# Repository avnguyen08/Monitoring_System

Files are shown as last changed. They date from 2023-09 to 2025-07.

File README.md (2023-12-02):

# Current Monitoring System 

Various current monitoring software products made on the ESP32 using varied electronic components including: LCDs, external ADC, potentiometers, capacitors, resistors, plug-and-play connectors, and 7 segment displays

### Version A (7-Segment Display)
ESP32 Feather Board paired with a Featherwing 7-Segment Display to display the amount of amps passing through a material and the amount of time the amps passed through for. The external ADC can handle voltage bursts as low as 2mv at 180 ms 
- Language: C++
 - Components: ESP32 Feather, external ADC, 7-segment display featherwing, LEDs, potentiometers, capacitors, resistors, socket connectors, pin head connectors, 5V power adapter.
- Description:
    Cycles between displaying the current and time on a 7-Segment display. Display times are customizable using potentiometers on back of PCB
    External pull down resistors and decoupling cacpacitors used for signal integrity.
    Dip switch in back to provide customizability with regard to different shunts and machines. 
    Machines operate at thousands of current and use a shunt to have readable levels, ranging from 2mv to 4V. 
    Pin headers and socket headers for easy installation into varied machines.

### Version B (LCD Display)
- Language: C++
- Components: LilyGo T Display S3, external ADC, capacitors, resistors, socket connectors, pin head connectors, 5V power adapter.
- Description: 
  Communication with LCD using SPI. Communication with external ADC using I2C. ESP32 simulatenously displays the amount of amps passing through a material and the amount of time the amps passed through for. Decoupling Capacitors and pull down resistors used for signal integrety. Pin headers and 
  socket headers for easy installation into varied machines.

### Version C (LCD Display + Hardware Filter)
 - Language: C++
 - Components: LilyGo T Display S3, external ADC, capacitors, resistors, socket connectors, pin head connectors, 5V power adapter, op amps, potentiometers.
 - Description: Communication with LCD using SPI, Communication with external ADC using I2C. ESP32 simulatenously displays the amount of amps passing through a material and the amount of time the amps passed through for. Decoupling Capacitors and pull down resistors used for signal integrety. Pin headers and socket headers for easy installation into varied machines. Integrated legacy hardware filter used to help clean up dirty signals caused by electromagnetic interference.

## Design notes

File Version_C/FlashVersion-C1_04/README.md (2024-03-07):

## Flash Firmware to LCD Tutorial for Windows(Current Monitoring System (Ver.C 1.04)

1. Unplug LCD screen from PCB board
2. Hold Down BOOT Button (Reference picture in folder)
3. Plug in your PC's USB-C cable into LCD Screen
4. Release BOOT Button
5. Click Flash.bat file to flash firmware

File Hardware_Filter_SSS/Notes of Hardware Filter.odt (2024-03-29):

R22 and R27 at 5k causes output to max out around .68 V even with potentiometer calibrating

The last op amp seems to output at a ratio of 7.196 at 500 mv dc input

its ratio is 7.197 at 100mv dc input

its ratio is 7.19 at 10 mv dc input

From input to first opamp output comparison

500mv to 2656 mV

100mv to 531.37 mV

10mv 53.137 mV

Meaning ratio is 5.3137

with -10mV input

3rd opamp output 53.136mV

Long line stays at 53.11

Long line feeds into + input of 5th opamp, also has .1uF capacitor

5th Opamp output is 72.78 mV

Theoretical Calculations:

1st Op Amp: 1+ 110/25.5 = 5.3137 ratio

2nd Op Amp: Full Wave Rectifier

3rd Op Amp: Unity Gain

4th Op Amp: Low Pass Filter?

5th Op Amp: Low Pass Filter? And 1+3.65/10 = 1.365 gain

Meaning DC input voltage to 5th Op Amp Output is: 5.3137*1.365 = 7.2532 gain

Sine Wave LTSPICE Test:

Note: 1st Op Amp may be 1 + 110/(22.5k||187k+13k[reactance of .2uF capacitor]) = 1 + 110k/22.62k = 5.86 Gain

Input of 100mv Amplitude sine wave

1st Op Amp: Output is 587 mV Amplitude

2nd Op Amp: 587 mV (rectified)

3rd Op Amp: 587 mV

Long Line 336.5mV

400mV

1v at input is .748v at 2x

2v at input is 1.38v at 2x

3V at input is 1.38V at 2x

.5v at input is .374 at 2x

Results suggest it is linear when changing the multiplier value of 1st opamp. (R3 from 110k to 25.5k). Should double the input going across the 1st op amp

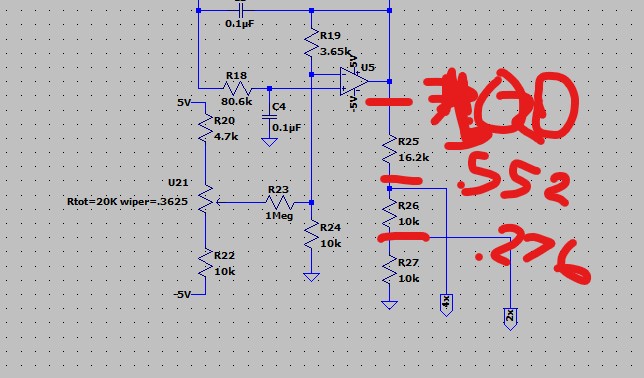
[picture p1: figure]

Working on Solution:

2.82V amplitude (2V rms) produces 16.56V

if I can turn 2.82V input into 5v then solution should work (1.77 gain)

1.77 = 1 + R3/25.5k

R3 = .77*25.5k = 19.635k

To do that I use 16.56V

LTSPICE Results

Right now best results is R3 as 17k and doing this voltage divider for last op amp

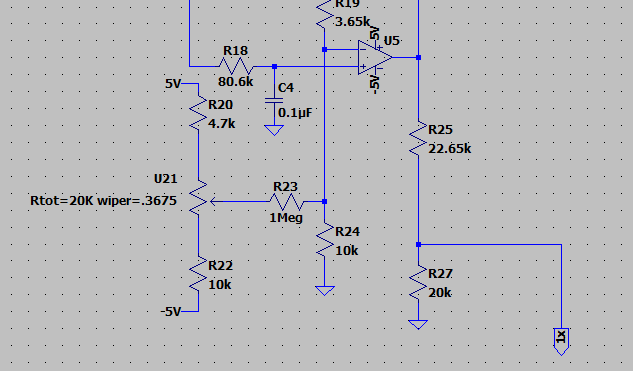
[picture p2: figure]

Next steps:

I notice with dc values when I run 1V I expect 1V at the 1x output but I get 1.058V. That is a 58mV difference. Compared to the original of 1.987V which is a 11 mV difference. I hypothesize the difference is because I tuned the resistors in the circuit for sine wave outputs rather than dc. Do to impedance issues there are probably some differences. One way I think to change it is to mess with the first op amp r5 and c1 values.

First test. Default values of 187k and .1uF gets max value of 5.2456. Calculating the impedance, I get the value of 188.8k, 188.8k in parallel with 25.5k is 22.47

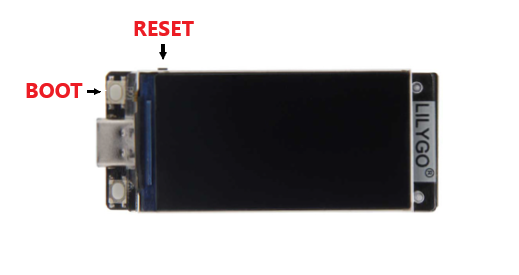
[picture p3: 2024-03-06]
Version_C/FlashVersion-C1_04/LCD Diagram.png

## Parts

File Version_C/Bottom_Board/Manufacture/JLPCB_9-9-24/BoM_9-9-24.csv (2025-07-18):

Comment | Designator | Footprint
LM324DR | U1,U2 | Package_SO:SOIC-14_3.9x8.7mm_P1.27mm
ADS1015IDGSR | U3 | bot_lib:DGS0010A_N
.75 Vdc | TP2 | TestPoint:TestPoint_Loop_D2.54mm_Drill1.5mm_Beaded
.55 Vdc | TP1 | TestPoint:TestPoint_Loop_D2.54mm_Drill1.5mm_Beaded
SW_DIP_x04 | SW1 | Button_Switch_THT:SW_DIP_SPSTx04_Slide_9.78x12.34mm_W7.62mm_P2.54mm
20K POT | RV1,RV2 | bot_lib:Potentiometer_Bourns_3386P_Vertical
22K | R8,R18 | Resistor_SMD:R_0603_1608Metric
4.7K | R6,R9 | Resistor_SMD:R_0603_1608Metric
80.6K | R5,R7,R16,R20 | Resistor_SMD:R_0603_1608Metric
10K | R3,R12,R13,R17,R19,R21,R23,R26,R27,R28,R29 | Resistor_SMD:R_0603_1608Metric
1M | R14,R22 | Resistor_SMD:R_0603_1608Metric
20k | R10B1 | Resistor_SMD:R_0603_1608Metric
20K | R10A1,R11 | Resistor_SMD:R_0603_1608Metric
3.9M | R30 | Resistor_SMD:R_0603_1608Metric
3.65K | R25 | Resistor_SMD:R_0603_1608Metric
16.2K | R24 | Resistor_SMD:R_0603_1608Metric
110K | R15 | Resistor_SMD:R_0603_1608Metric
1.82K | R4 | Resistor_SMD:R_0603_1608Metric
25.5K | R2 | Resistor_SMD:R_0603_1608Metric
187K | R1 | Resistor_SMD:R_0603_1608Metric
Conn_02x03_Top_Bottom | J1,J5 | bot_lib:PinSocket_2x03_P2.54mm_Vertical
DIN-5 | J4 | bot_lib:DIN_5_PIN
Screw_Terminal_01x04 | J3 | bot_lib:Terminal_Strip_4_Pin
Conn_01x03_Pin | J2 | Connector_PinHeader_2.54mm:PinHeader_1x03_P2.54mm_Vertical
1N4148WS | D1 | bot_lib:Diode_1N4148WS
0.1uF | C3,C4,C5,C7,C8,C10,C11 | Capacitor_SMD:C_0603_1608Metric
330uF | C1,C2 | Capacitor_THT:CP_Radial_D10.0mm_P5.00mm
1uF | C9 | Capacitor_SMD:C_0603_1608Metric
0.002uF | C6 | Capacitor_SMD:C_0603_1608Metric

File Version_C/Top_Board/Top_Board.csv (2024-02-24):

Source: | C:\Users\aaron\OneDrive\Desktop\repos\Monitoring_System\Version_B\Top_Board\Top_Board.kicad_sch
Date: | 2/23/2024 12:11:28 PM
Tool: | Eeschema (7.0.0)
Generator: | D:\MyPrograms\7.0\bin\scripting\plugins/bom_csv_grouped_by_value.py
Component Count: | 3
Collated Components:
Item | Qty | Reference(s) | Value | LibPart | Footprint | Datasheet | DNP
1 | 2 | J1, J2 | 90_Deg_Conn | Connector_Generic:Conn_02x03_Odd_Even | Connector_PinHeader_2.54mm:PinHeader_2x03_P2.54mm_Horizontal | ~
2 | 1 | U1 | T-Display-S3 | Voltage_Sensor_Timer:T-Display-S3 | Voltage_Sensor_Timer:T-Display-S3

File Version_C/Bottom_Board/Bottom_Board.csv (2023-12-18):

Source: | C:\Users\aaron\OneDrive\Desktop\repos\Work_SSS\Version_B\Bottom_Board\Bottom_Board.kicad_sch
Date: | 12/5/2023 2:48:59 PM
Tool: | Eeschema (7.0.0)
Generator: | D:\MyPrograms\7.0\bin\scripting\plugins/bom_csv_grouped_by_value.py
Component Count: | 46
Collated Components:
Item | Qty | Reference(s) | Value | LibPart | Footprint | Datasheet | DNP | Sim.Device | Sim.Pins
1 | 6 | C1, C4, C6, C7, C8, C9 | 0.1uF | Device:C | Capacitor_SMD:C_0603_1608Metric | ~
2 | 2 | C2, C3 | 330uF | Device:C_Polarized_US | Capacitor_THT:CP_Radial_D10.0mm_P5.00mm | ~
3 | 1 | C5 | 0.002uF | Device:C | Capacitor_SMD:C_0603_1608Metric | ~
4 | 1 | D1 | 1N914 | Diode:1N914 | Diode_SMD:D_0603_1608Metric | http://www.vishay.com/docs/85622/1n914.pdf |  |  | D | 1=K 2=A
5 | 2 | J1, J2 | Conn_02x03_Top_Bottom | Connector_Generic:Conn_02x03_Odd_Even | Connector_PinSocket_2.54mm:PinSocket_2x03_P2.54mm_Vertical | ~
6 | 1 | J3 | Screw_Terminal_01x06 | Connector:Screw_Terminal_01x06 | Connector_Phoenix_MSTB:PhoenixContact_MSTBA_2,5_6-G-5,08_1x06_P5.08mm_Horizontal | ~
7 | 1 | J5 | DIN-5 | Connector:DIN-5 | bot_lib:DIN_5_PIN | http://www.mouser.com/ds/2/18/40_c091_abd_e-75918.pdf
8 | 1 | JP1 | Jumper_3_Open | Jumper:Jumper_3_Open | Connector_PinHeader_2.54mm:PinHeader_1x03_P2.54mm_Vertical | ~
9 | 4 | R1, R20, R21, R22 | 80.6K | Device:R_US | Resistor_SMD:R_0603_1608Metric | ~
10 | 2 | R2, R17 | 4.7K | Device:R_US | Resistor_SMD:R_0603_1608Metric | ~
11 | 7 | R3, R9, R13, R14, R16, R19, R24 | 10K | Device:R_US | Resistor_SMD:R_0603_1608Metric | ~
12 | 1 | R4 | 30.1K | Device:R_US | Resistor_SMD:R_0603_1608Metric | ~
13 | 1 | R5 | 20K | Device:R_US | Resistor_SMD:R_0603_1608Metric | ~
14 | 1 | R6 | 1M | Device:R_US | Resistor_SMD:R_0603_1608Metric | ~
15 | 1 | R7 | 25.5K | Device:R_US | Resistor_SMD:R_0603_1608Metric | ~
16 | 1 | R8 | 3.65K | Device:R_US | Resistor_SMD:R_0603_1608Metric | ~
17 | 1 | R10 | 187K | Device:R_US | Resistor_SMD:R_0603_1608Metric | ~
18 | 1 | R11 | 110K | Device:R_US | Resistor_SMD:R_0603_1608Metric | ~
19 | 1 | R12 | 16.2K | Device:R_US | Resistor_SMD:R_0603_1608Metric | ~
20 | 2 | R15, R18 | 22K | Device:R_US | Resistor_SMD:R_0603_1608Metric | ~
21 | 1 | R23 | 1.82K | Device:R_US | Resistor_SMD:R_0603_1608Metric | ~
22 | 2 | RV1, RV2 | 20K | Device:R_Potentiometer_US | Potentiometer_THT:Potentiometer_Bourns_3386P_Vertical | ~
23 | 1 | SW2 | SW_DIP_x04 | Switch:SW_DIP_x04 | Button_Switch_THT:SW_DIP_SPSTx04_Slide_9.78x12.34mm_W7.62mm_P2.54mm | ~
24 | 1 | TP1 | .75 Vdc | Connector:TestPoint | TestPoint:TestPoint_Loop_D2.54mm_Drill1.5mm_Beaded | ~
25 | 1 | TP2 | .55 Vdc | Connector:TestPoint | TestPoint:TestPoint_Loop_D2.54mm_Drill1.5mm_Beaded | ~
26 | 2 | U1, U2 | LM324 | Amplifier_Operational:LM324 | Package_SO:SOIC-14_3.9x8.7mm_P1.27mm | http://www.ti.com/lit/ds/symlink/lm2902-n.pdf

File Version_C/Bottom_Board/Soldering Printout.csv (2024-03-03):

Reference | Value | Qty
C1,C2 | 330uF | 2
C3,C4,C5,C7,C8,C10,C11 | 0.1uF | 7
C6 | 0.002uF | 1
C9 | 1uF | 1
D1 | 1N4148WS | 1
J1,J5 | Conn_02x03_Top_Bottom | 2
J2 | Conn_01x03_Pin | 1
J3 | Screw_Terminal_01x04 | 1
J4 | DIN-5 | 1
R1 | 187K | 1
R2 | 25.5K | 1
R3,R12,R13,R17,R19,R21,R23 | 10K | 7
R4 | 1.82K | 1
R5,R7,R16,R20 | 80.6K | 4
R6,R9 | 4.7K | 2
R8,R18 | 22K | 2
R10 | 30.1K | 1
R11,RV1,RV2 | 20K | 3
R14,R22 | 1M | 2
R15 | 110K | 1
R24 | 16.2K | 1
R25 | 3.65K | 1
R26,R27,R28,R29 | 10k | 4
R30 | 3.9M | 1
SW1 | SW_DIP_x04 | 1
TP1 | .55 Vdc | 1
TP2 | .75 Vdc | 1
U1,U2 | LM324 | 2
U3 | ADS1015IDGSR | 1

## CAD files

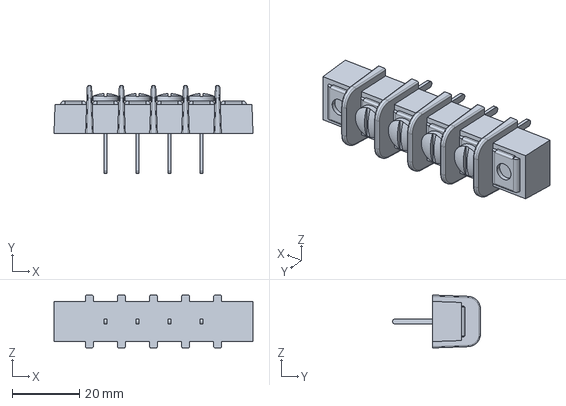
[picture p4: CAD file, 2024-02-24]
Version_C/Bottom_Board/Bottom_Board_3d/4_Pin_Terminal_Block.stp
59.2 x 26.2 x 15.7 mm

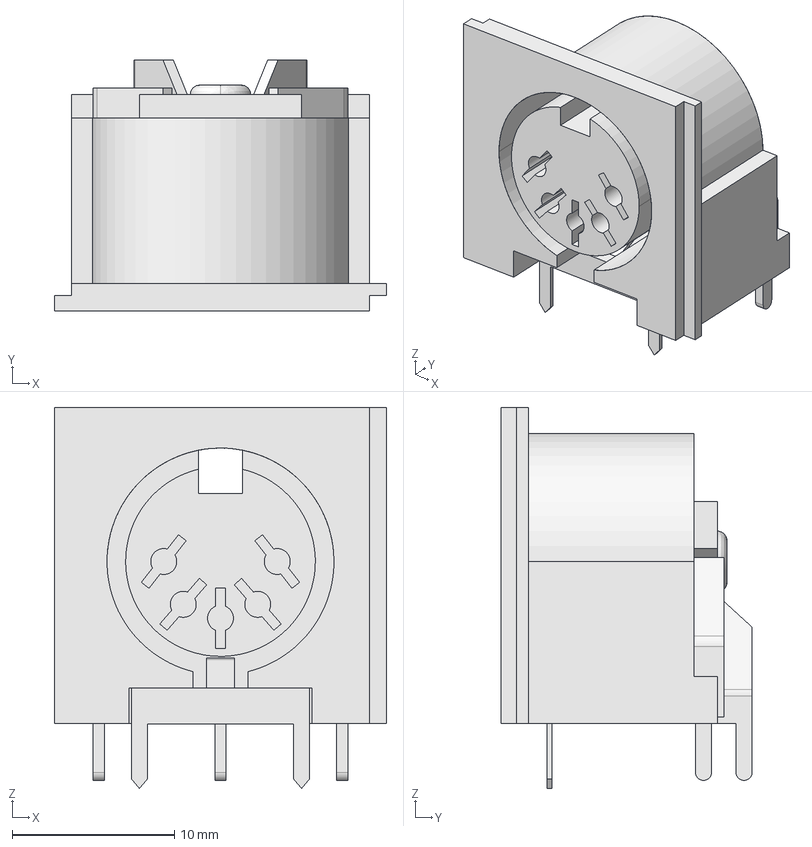
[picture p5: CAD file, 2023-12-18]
Version_C/Misc/DIN_5_PIN.FCStd
20.5 x 15.5 x 23.5 mm

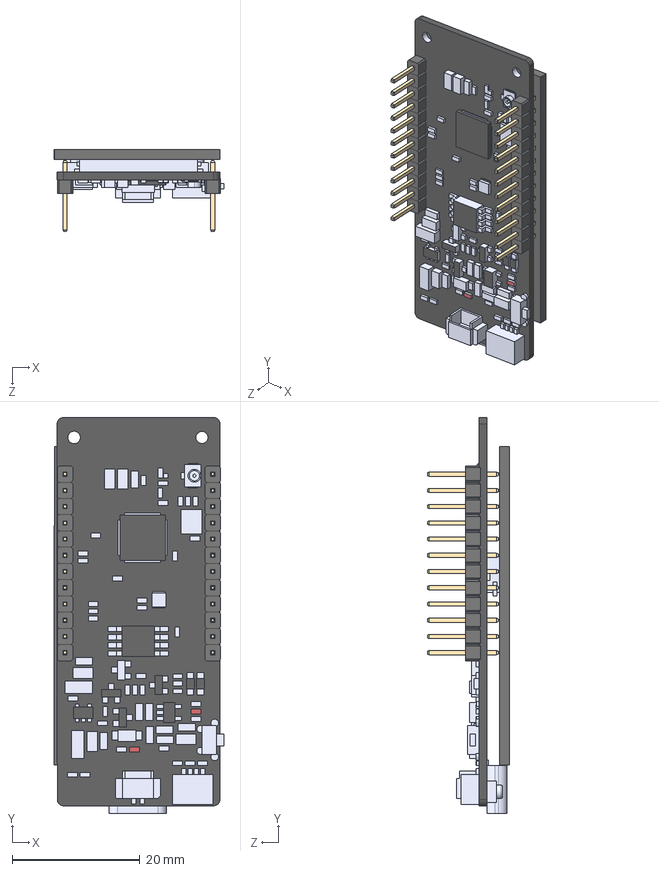
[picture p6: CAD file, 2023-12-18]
Version_C/Top_Board/Top_Board_3d/T-Display-S3.STEP
26.5 x 62.0 x 12.9 mm
MainBoard_3D
Ecran
1_Male_Pin_2.54_mm x 24

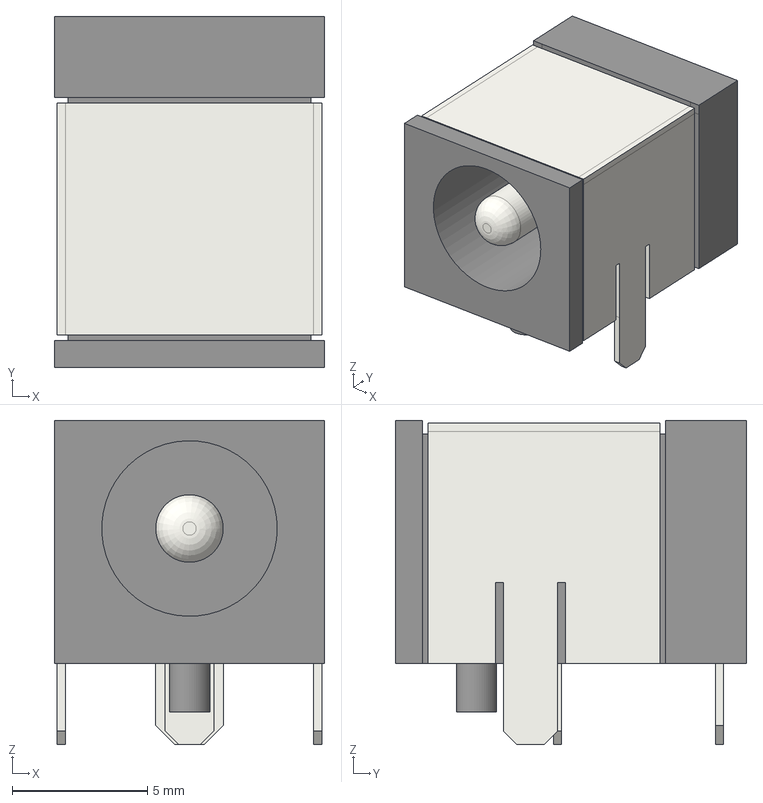
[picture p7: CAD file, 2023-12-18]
Version_C/Bottom_Board/Bottom_Board_3d/BarrelJack_CUI_PJ-063BH_Horizontal.step
10.0 x 13.0 x 12.0 mm

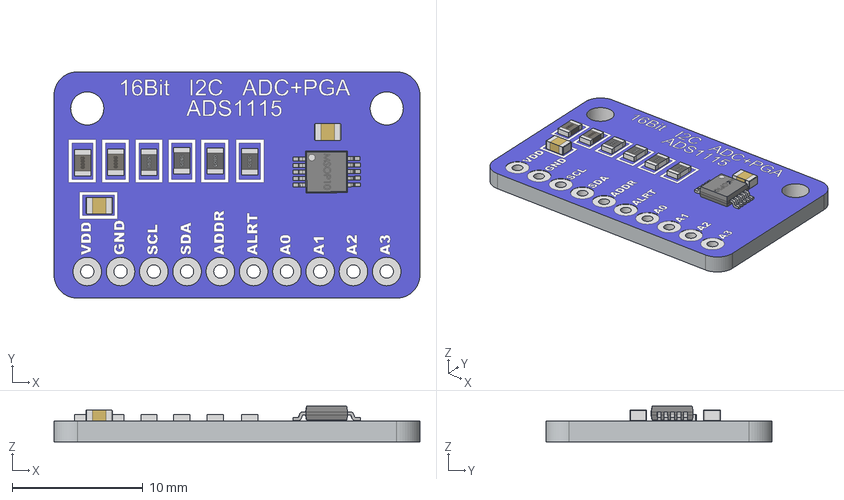
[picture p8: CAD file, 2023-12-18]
Version_C/Top_Board/Top_Board_3d/16Bit I2C ADC+PGA - ADS1115.stp
27.9 x 17.3 x 2.74 mm
ADS1115
0805 Capacitor x 2
0805 Inductor x 2
0805 Resistor x 4
MSOP10

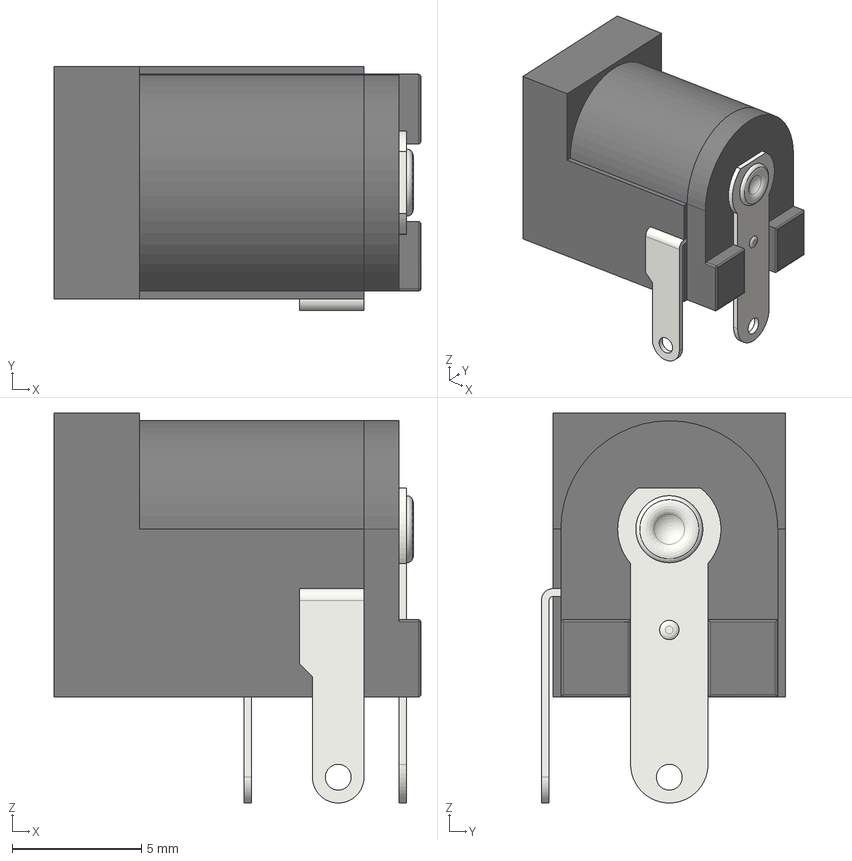
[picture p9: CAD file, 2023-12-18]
Version_C/Bottom_Board/Bottom_Board_3d/DC_Power_Jack_PCB_Mounted_2.1mm.step
14.2 x 9.45 x 15.1 mm
Plastic_Body_1of2
Plastic_Body_2of2
PIN_01
PIN_03
PIN_02
Boner

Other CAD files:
Version_C/Bottom_Board/Bottom_Board_3d/BarrelJack_CUI_PJ-063AH_Horizontal.step
Version_C/Bottom_Board/Bottom_Board_3d/DIN_5_PIN.step
Version_B/Bottom_Board/Bottom_Board_3d/DIN_5_PIN.step
Version_B/Bottom_Board/Bottom_Board_3d/BarrelJack_CUI_PJ-063AH_Horizontal.step

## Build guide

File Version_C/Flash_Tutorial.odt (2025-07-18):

Flash Firmware to LCD Tutorial for Windows (Current Monitoring System (Ver. C 1.09)


1. Unplug LCD screen from PCB board
2. Hold Down BOOT Button
3. Plug in your PC's USB-C cable into LCD Screen
4. Release BOOT Button
5. Click Flash_LCD file to flash firmware

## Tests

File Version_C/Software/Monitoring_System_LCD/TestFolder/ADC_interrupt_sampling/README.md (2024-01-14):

# Testing for faster samples using interrupts #

- Samples were not faster, around same speed

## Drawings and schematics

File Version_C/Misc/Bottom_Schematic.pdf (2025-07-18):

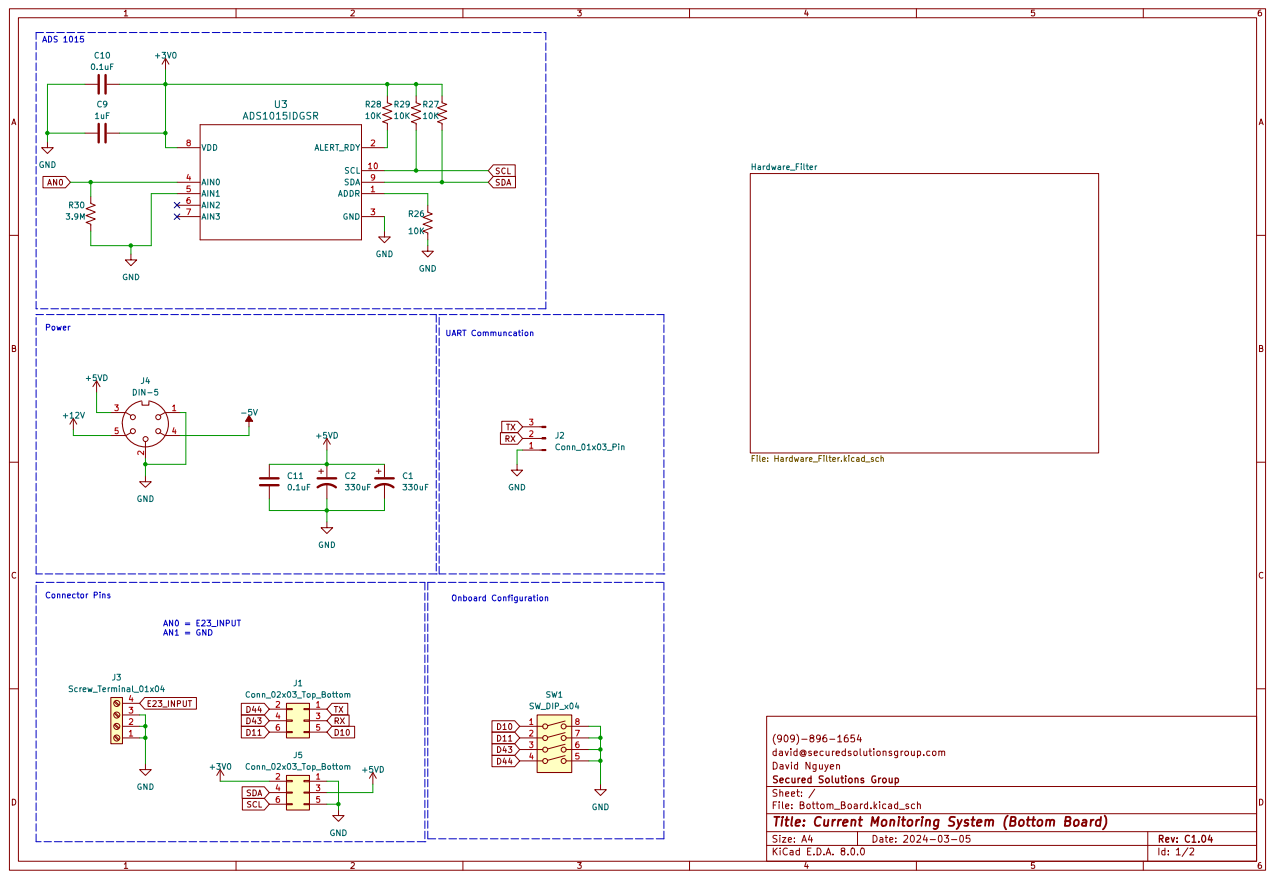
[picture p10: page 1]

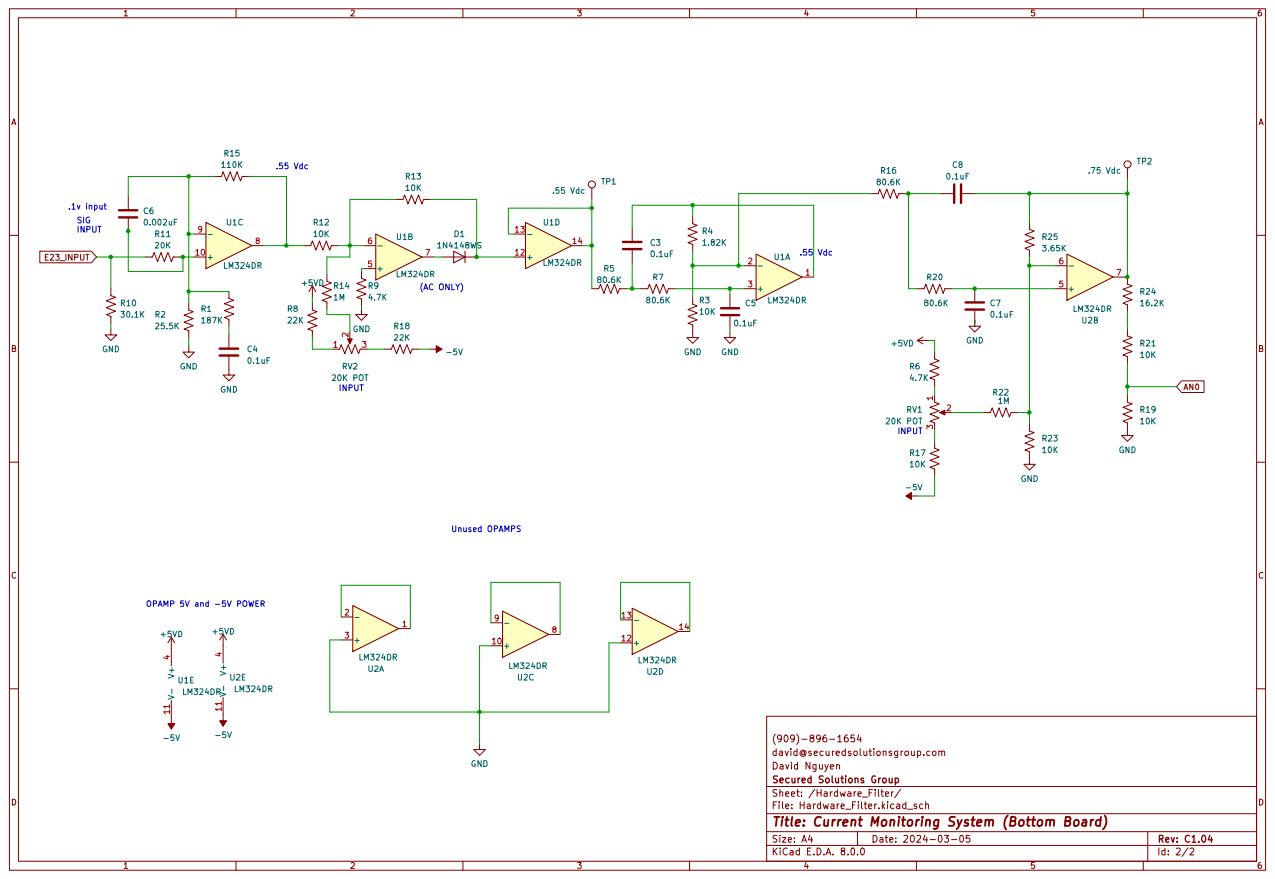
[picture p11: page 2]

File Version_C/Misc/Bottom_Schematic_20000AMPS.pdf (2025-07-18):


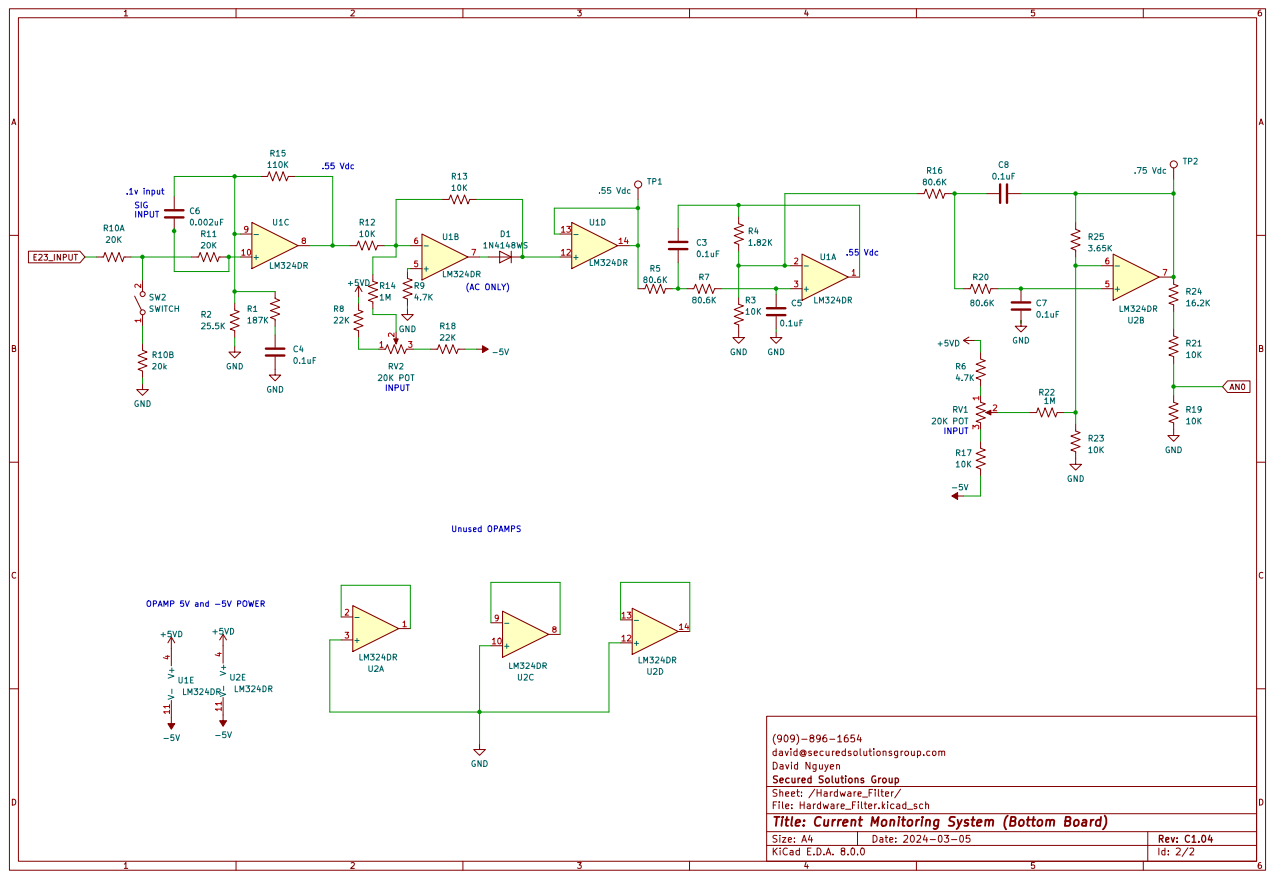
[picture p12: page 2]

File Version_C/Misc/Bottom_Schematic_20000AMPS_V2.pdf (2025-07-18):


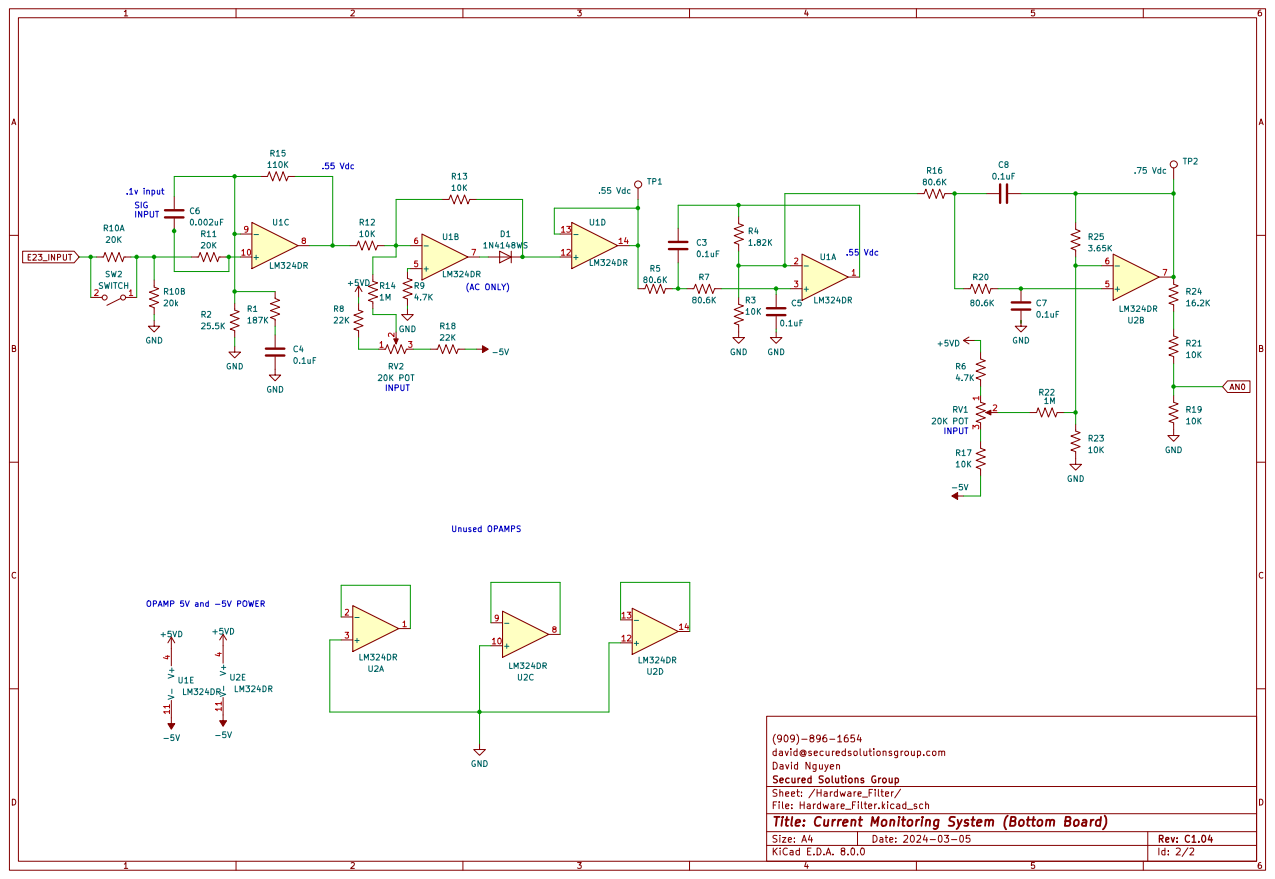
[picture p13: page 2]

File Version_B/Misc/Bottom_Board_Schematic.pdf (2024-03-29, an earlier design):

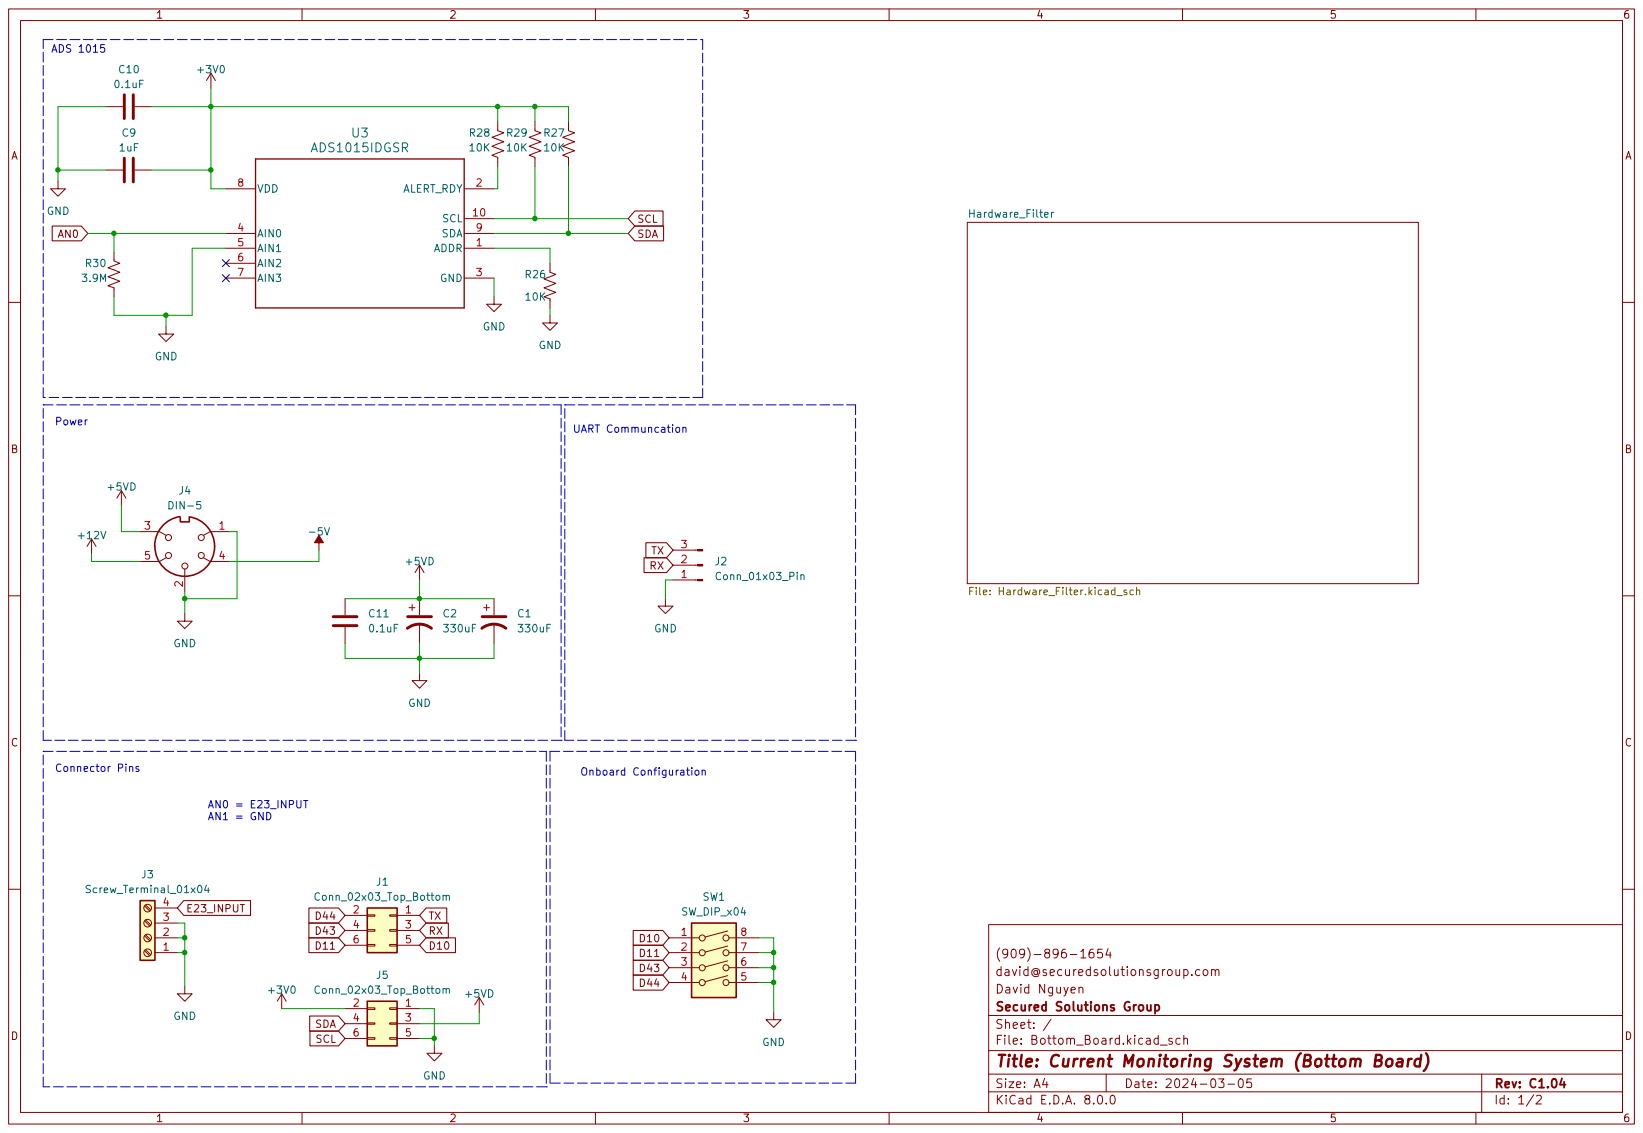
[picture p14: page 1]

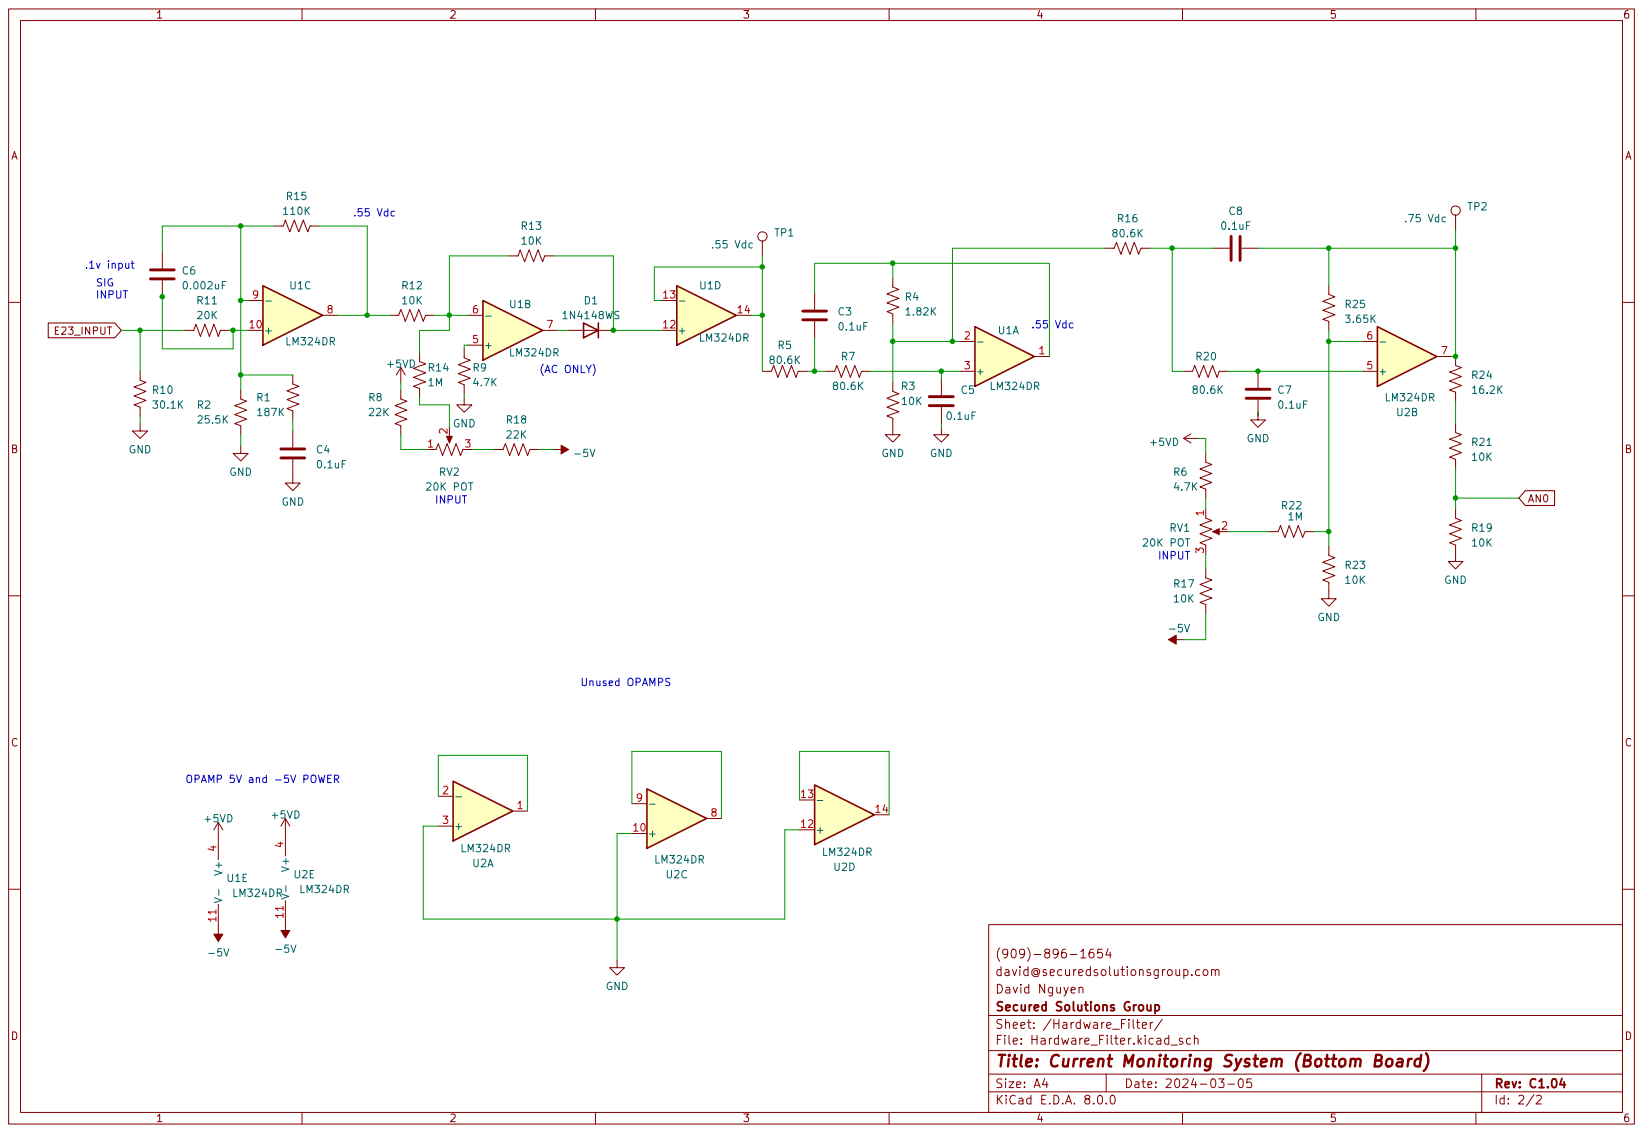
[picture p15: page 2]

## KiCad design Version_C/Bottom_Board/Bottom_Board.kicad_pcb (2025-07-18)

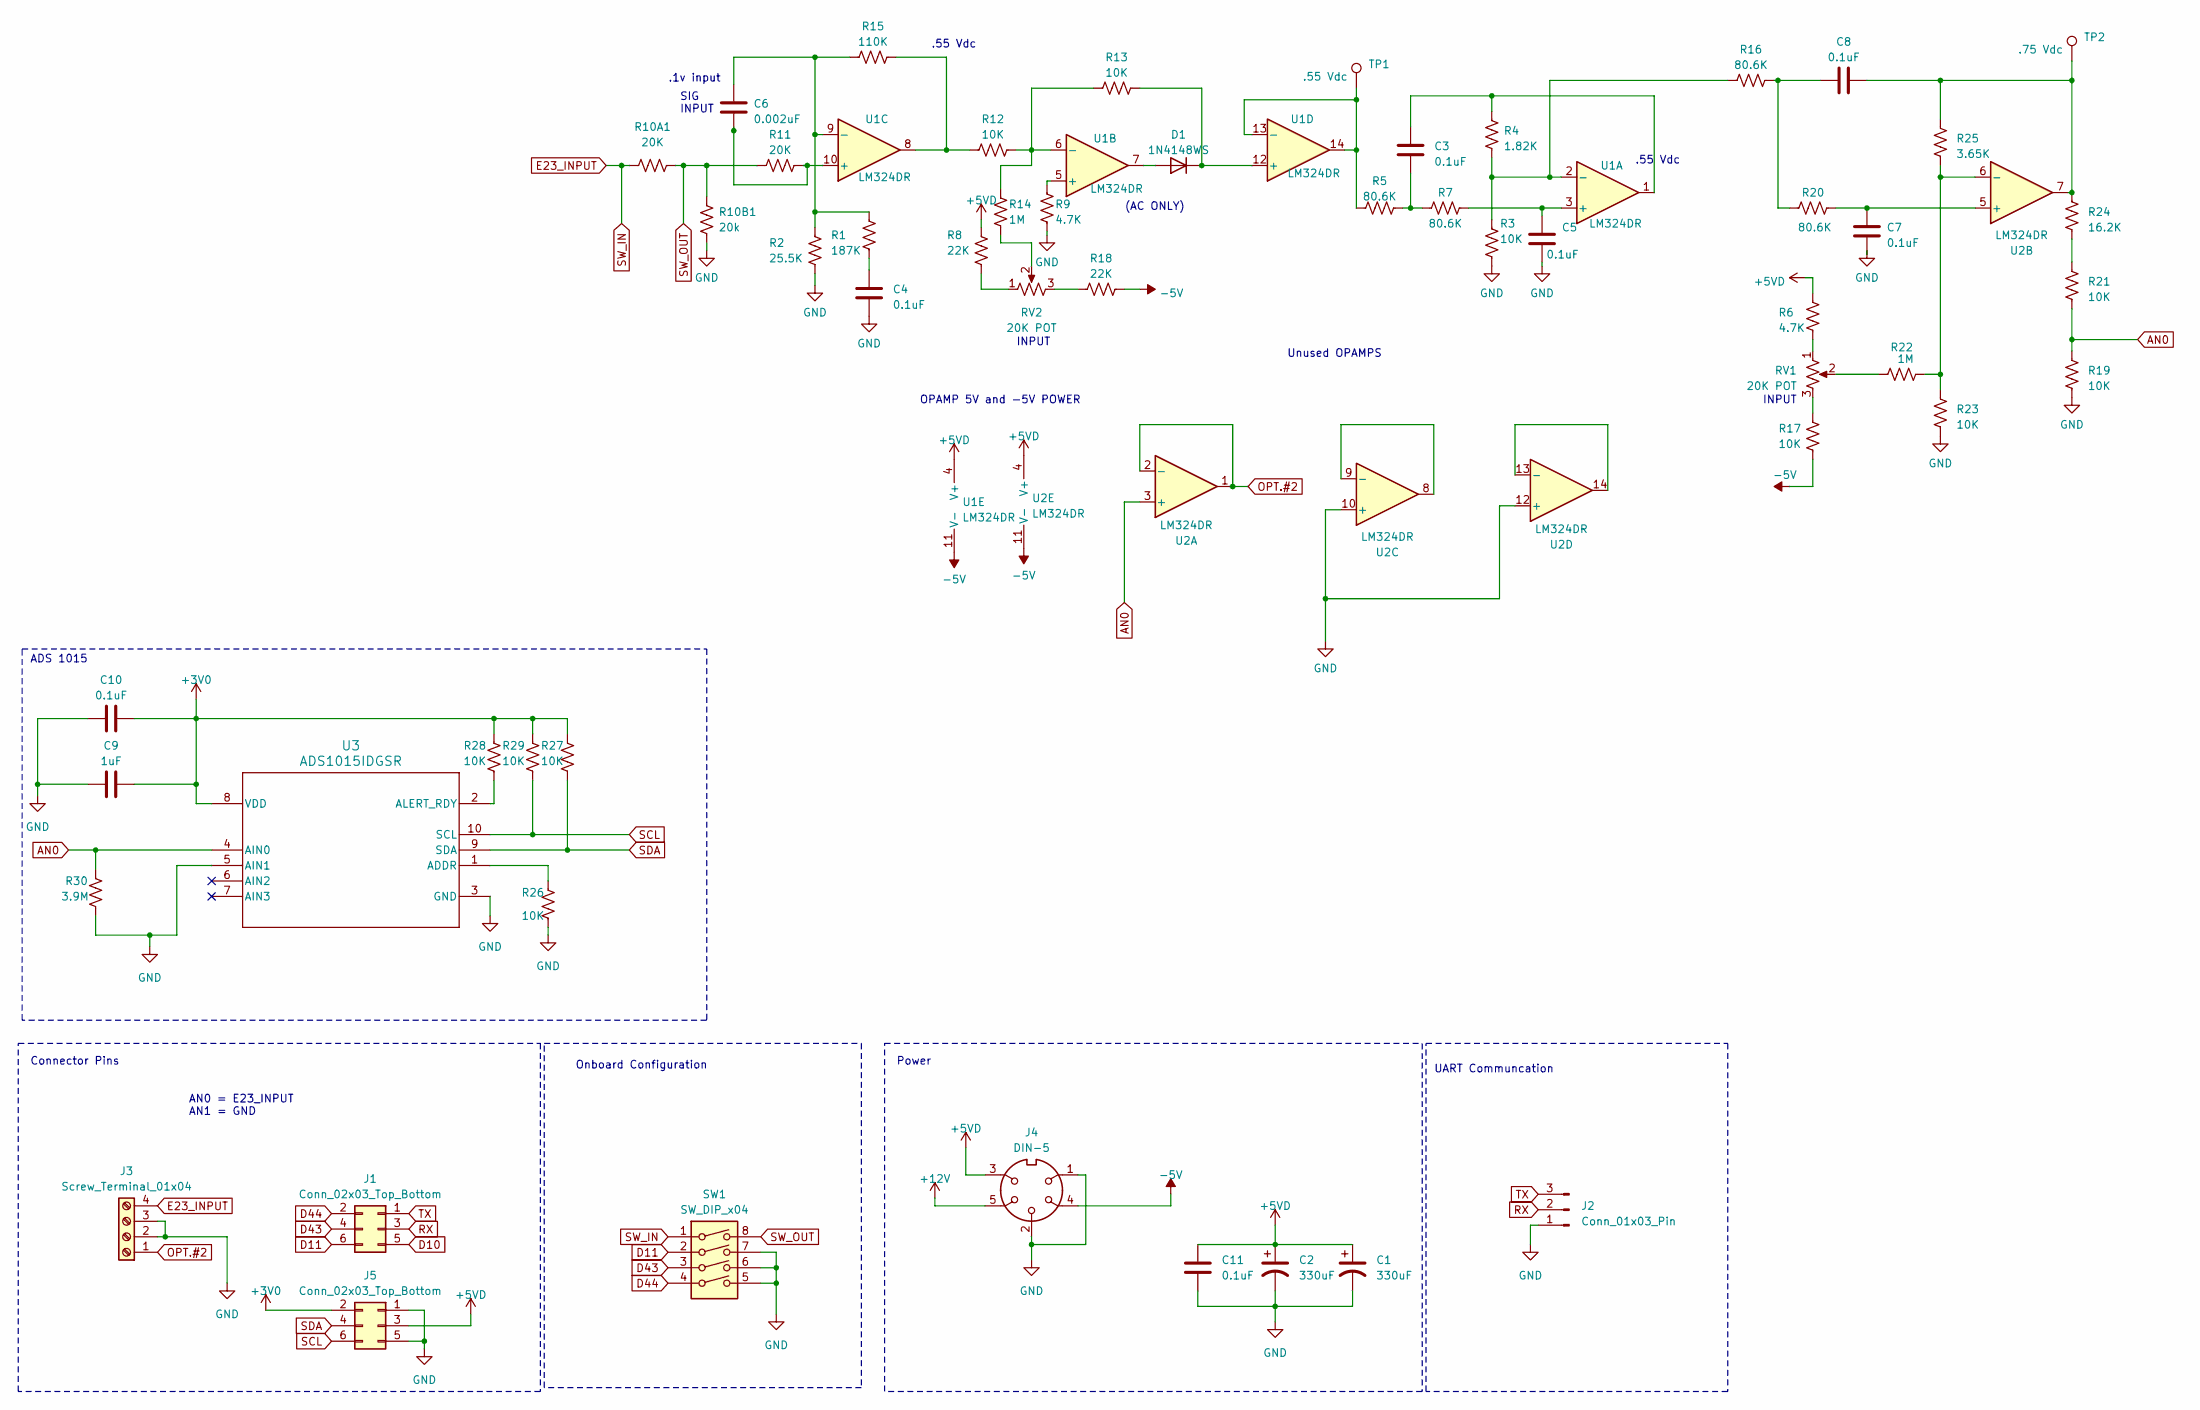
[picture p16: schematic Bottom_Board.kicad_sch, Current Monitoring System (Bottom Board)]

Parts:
C1, C2: 330uF; CP_Radial_D10.0mm_P5.00mm
C3, C4, C5, C7, C8, C10, C11: 0.1uF; C_0603_1608Metric
C6: 0.002uF; C_0603_1608Metric
C9: 1uF; C_0603_1608Metric
D1: 1N4148WS; Diode_1N4148WS
J1, J5: Conn_02x03_Top_Bottom; PinSocket_2x03_P2.54mm_Vertical
J2: Conn_01x03_Pin; PinHeader_1x03_P2.54mm_Vertical
J3: Screw_Terminal_01x04; Terminal_Strip_4_Pin
J4: DIN-5; DIN_5_PIN
R1: 187K; R_0603_1608Metric
R2: 25.5K; R_0603_1608Metric
R3, R12, R13, R17, R19, R21, R23, R26, R27, R28, R29: 10K; R_0603_1608Metric
R4: 1.82K; R_0603_1608Metric
R5, R7, R16, R20: 80.6K; R_0603_1608Metric
R6, R9: 4.7K; R_0603_1608Metric
R8, R18: 22K; R_0603_1608Metric
R10A1, R11: 20K; R_0603_1608Metric
R10B1: 20k; R_0603_1608Metric
R14, R22: 1M; R_0603_1608Metric
R15: 110K; R_0603_1608Metric
R24: 16.2K; R_0603_1608Metric
R25: 3.65K; R_0603_1608Metric
R30: 3.9M; R_0603_1608Metric
RV1, RV2: 20K POT; Potentiometer_Bourns_3386P_Vertical
SW1: SW_DIP_x04; SW_DIP_SPSTx04_Slide_9.78x12.34mm_W7.62mm_P2.54mm
TP1: .55 Vdc; TestPoint_Loop_D2.54mm_Drill1.5mm_Beaded
TP2: .75 Vdc; TestPoint_Loop_D2.54mm_Drill1.5mm_Beaded
U1, U2: LM324DR; SOIC-14_3.9x8.7mm_P1.27mm
U3: ADS1015IDGSR; DGS0010A_N

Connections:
+3V0: C9.2, C10.2, J5.2, R27.1, R28.1, R29.1, U3.8 (VDD)
+5VD: C1.1, C2.1, C11.1, J4.3, J5.3, R6.2, R8.1, U1.4 (V+), U2.4 (V+)
+12V: J4.5
-5V: J4.4, R17.1, R18.2, U1.11 (V-), U2.11 (V-)
AN0: R19.2, R21.1, R30.1, U2.3 (+), U3.4 (AIN0)
D10: J1.5
D11: J1.6, SW1.2
D43: J1.4, SW1.3
D44: J1.2, SW1.4
E23_INPUT: J3.4, R10A1.1, SW1.1
GND: C1.2, C2.2, C4.2, C5.2, C7.1, C9.1, C10.1, C11.2, J2.1, J3.2, J3.3, J4.1, J4.2, J5.1, J5.5, R2.2, R3.2, R9.2, R10B1.2, R19.1, R23.1, R26.2, R30.2, SW1.5, SW1.6, SW1.7, U2.10 (+), U2.12 (+), U3.3 (GND), U3.5 (AIN1)
unnamed: C3.1, R4.2, U1.1
unnamed: C3.2, R5.2, R7.1
unnamed: C4.1, R1.2
unnamed: C8.1, R24.2, R25.2, TP2.1, U2.7
unnamed: C8.2, R16.1, R20.1
unnamed: D1.2 (A), U1.7
unnamed: D1.1 (K), R13.2, U1.12 (+)
unnamed: R6.1, RV1.1
unnamed: R8.2, RV2.1
unnamed: R12.1, R15.2, U1.8
unnamed: R14.2, RV2.2
unnamed: R17.2, RV1.3
unnamed: R18.1, RV2.3
unnamed: R21.2, R24.1
unnamed: R22.2, RV1.2
unnamed: C5.1, R7.2, U1.3 (+)
unnamed: R3.1, R4.1, R16.2, U1.2 (-)
unnamed: R9.1, U1.5 (+)
unnamed: R12.2, R13.1, R14.1, U1.6 (-)
unnamed: C6.2, R11.2, U1.10 (+)
unnamed: C6.1, R1.1, R2.1, R15.1, U1.9 (-)
unnamed: R5.1, TP1.1, U1.13 (-), U1.14
unnamed: C7.2, R20.2, U2.5 (+)
unnamed: R22.1, R23.2, R25.1, U2.6 (-)
unnamed: U2.8, U2.9 (-)
unnamed: U2.13 (-), U2.14
unnamed: R26.1, U3.1 (ADDR)
unnamed: R28.2, U3.2 (ALERT_RDY)
OPT.#2: J3.1, U2.1, U2.2 (-)
RX: J1.3, J2.2
SCL: J5.6, R29.2, U3.10 (SCL)
SDA: J5.4, R27.2, U3.9 (SDA)
SW_OUT: R10A1.2, R10B1.1, R11.1, SW1.8
TX: J1.1, J2.3

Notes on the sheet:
Connector Pins
INPUT
.55 Vdc
AN0 = E23_INPUT AN1 = GND
Unused OPAMPS
OPAMP 5V and -5V POWER
.1v input
Power
Onboard Configuration
(AC ONLY)
SIG INPUT
ADS 1015
UART Communcation

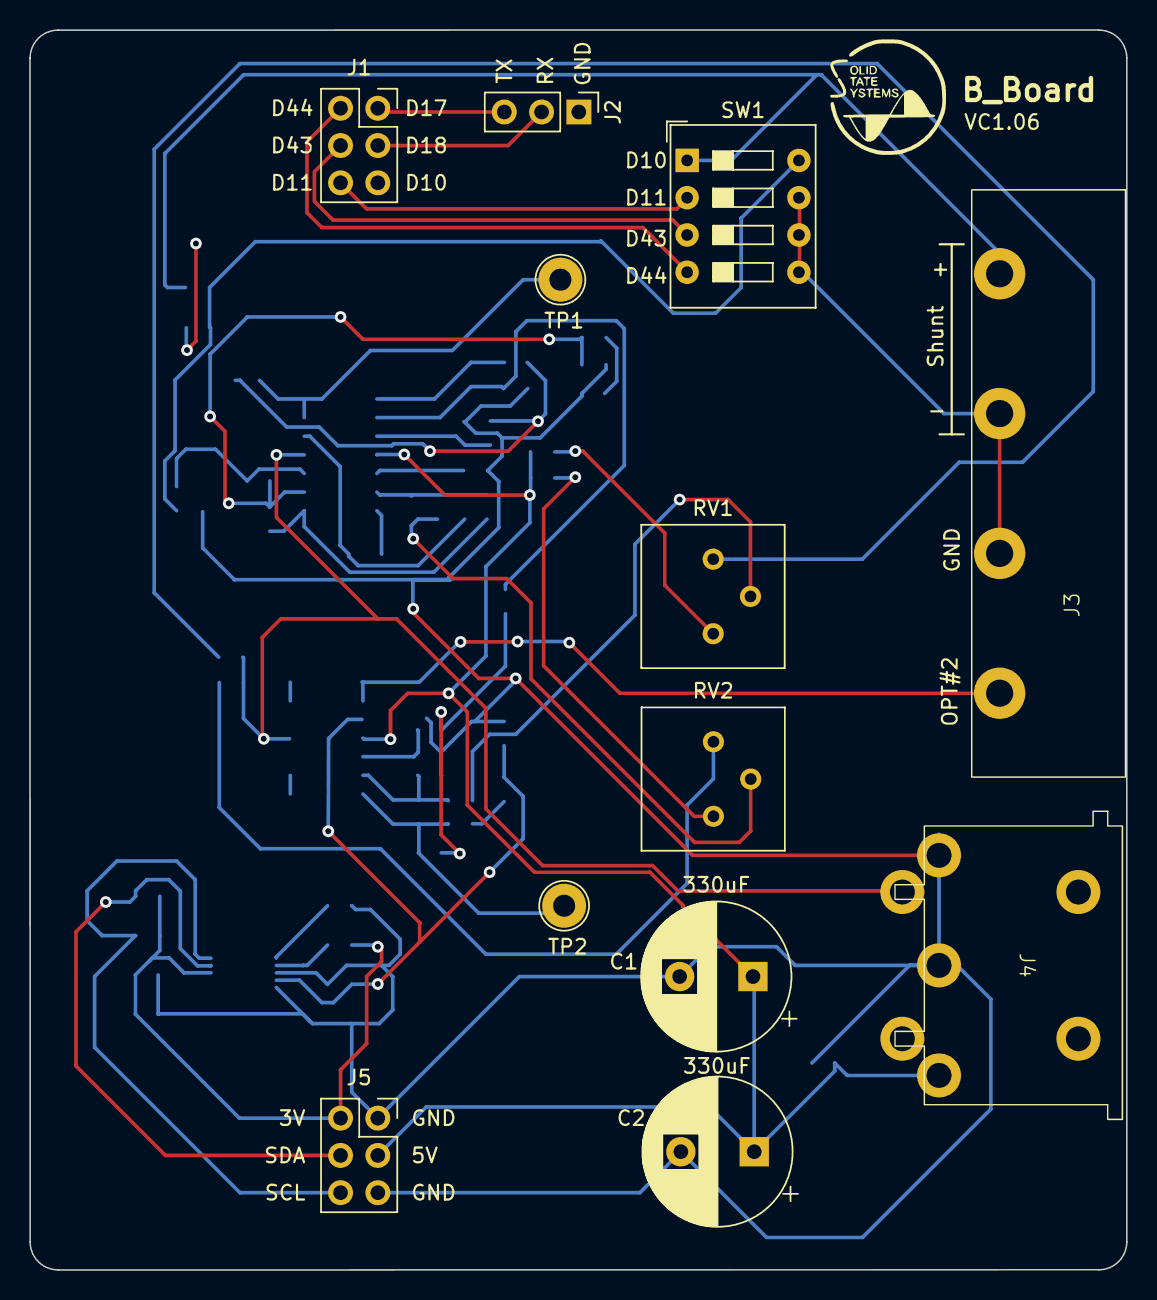
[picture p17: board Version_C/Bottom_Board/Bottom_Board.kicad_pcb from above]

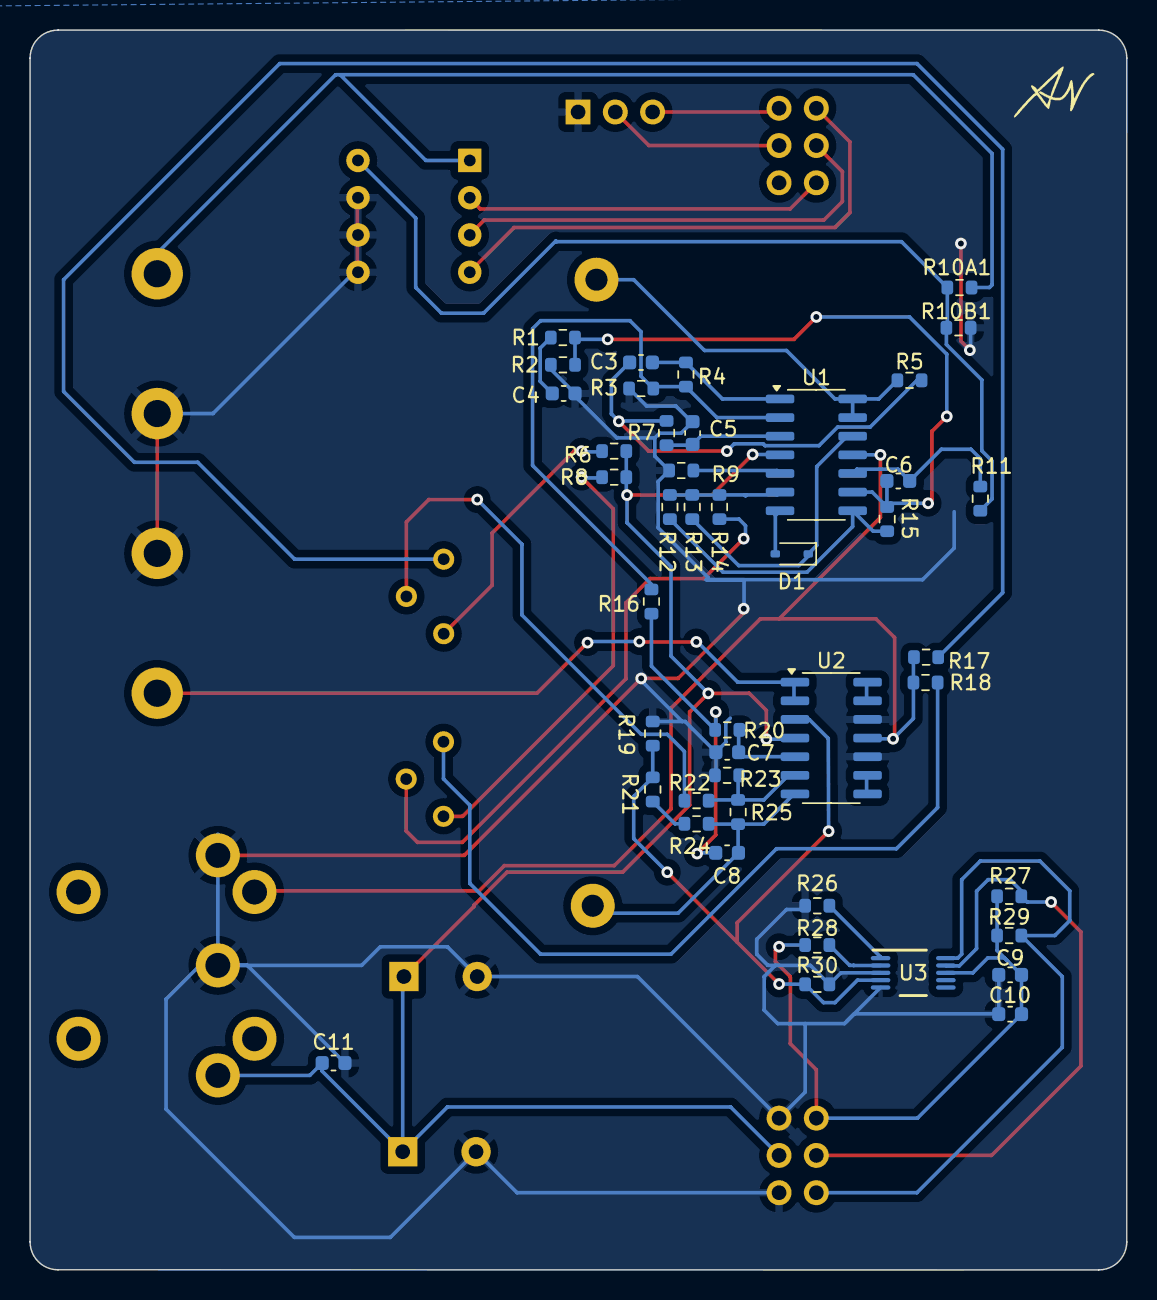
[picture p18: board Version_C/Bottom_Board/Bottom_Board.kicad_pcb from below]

Board: 2 copper layers, 74.8 x 84.5 mm, 56 parts (44 on the bottom side), 43 nets.

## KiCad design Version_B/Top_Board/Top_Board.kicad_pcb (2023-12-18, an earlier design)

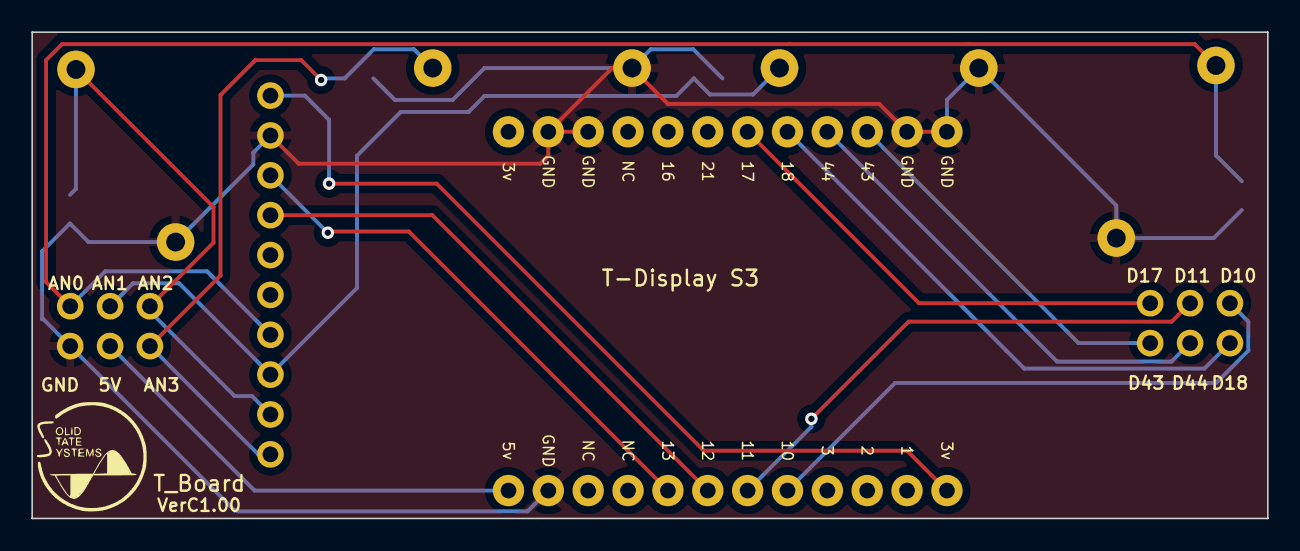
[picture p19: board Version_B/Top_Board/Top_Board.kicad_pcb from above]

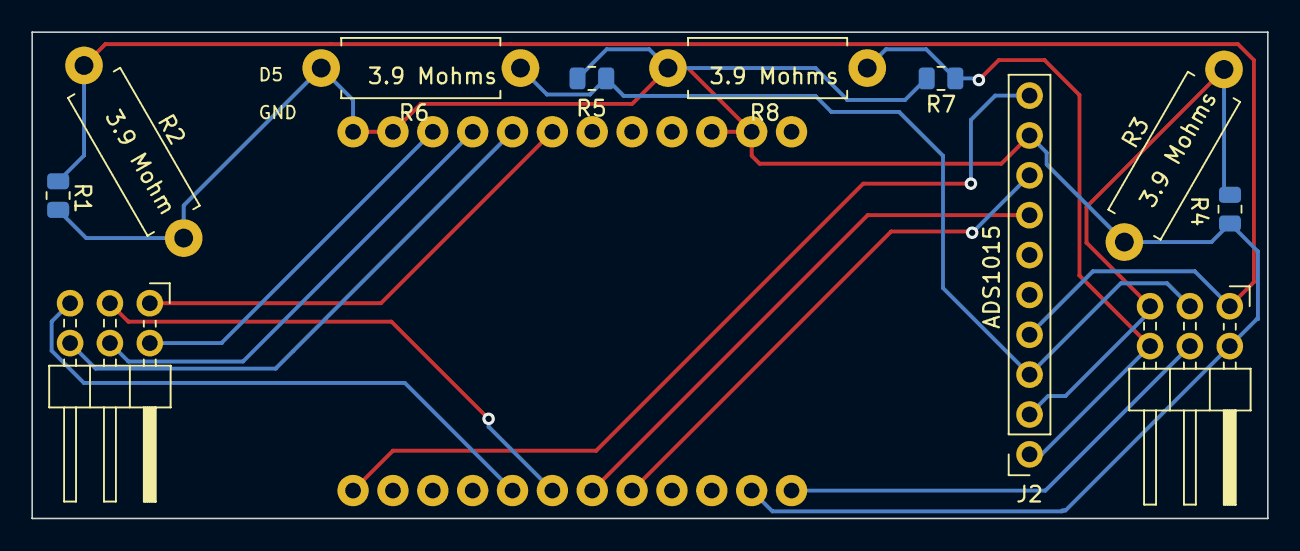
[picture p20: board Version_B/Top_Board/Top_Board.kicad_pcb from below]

Board: 2 copper layers, 78.7 x 31.0 mm, 12 parts (11 on the bottom side), 15 nets.

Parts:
J1, J4: 90_Deg_Conn; PinHeader_2x03_P2.54mm_Horizontal
J2: ADS1015; PinSocket_1x10_P2.54mm_Vertical_1
R1, R4, R5, R7: R; R_0805_2012Metric
R2, R3, R6, R8: R; R_Axial_DIN0411_L9.9mm_D3.6mm_P12.70mm_Horizontal
U1: T-Display-S3

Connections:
3V: J2.10, U1.1 (3v)
5V: J1.4, U1.12 (5V)
AN0: J1.1, J2.4, R1.1, R2.1
AN1: J1.3, J2.3, R5.1, R6.1
AN2: J1.5, J2.2, R3.1, R4.1
AN3: J1.6, J2.1, R7.1, R8.1
D10: J4.5, U1.5 (10)
D11: J4.3, U1.6 (11)
D17: J4.1, U1.18 (17)
D18: J4.6, U1.17 (18)
D43: J4.2, U1.15 (43)
D44: J4.4, U1.16 (44)
GND: J1.2, J2.9, R1.2, R2.2, R3.2, R4.2, R5.2, R6.2, R7.2, R8.2, U1.11 (GND), U1.13 (GND), U1.14 (GND), U1.22 (GND), U1.23 (GND)
SCL: J2.8, U1.8 (13)
SDA: J2.7, U1.7 (12)

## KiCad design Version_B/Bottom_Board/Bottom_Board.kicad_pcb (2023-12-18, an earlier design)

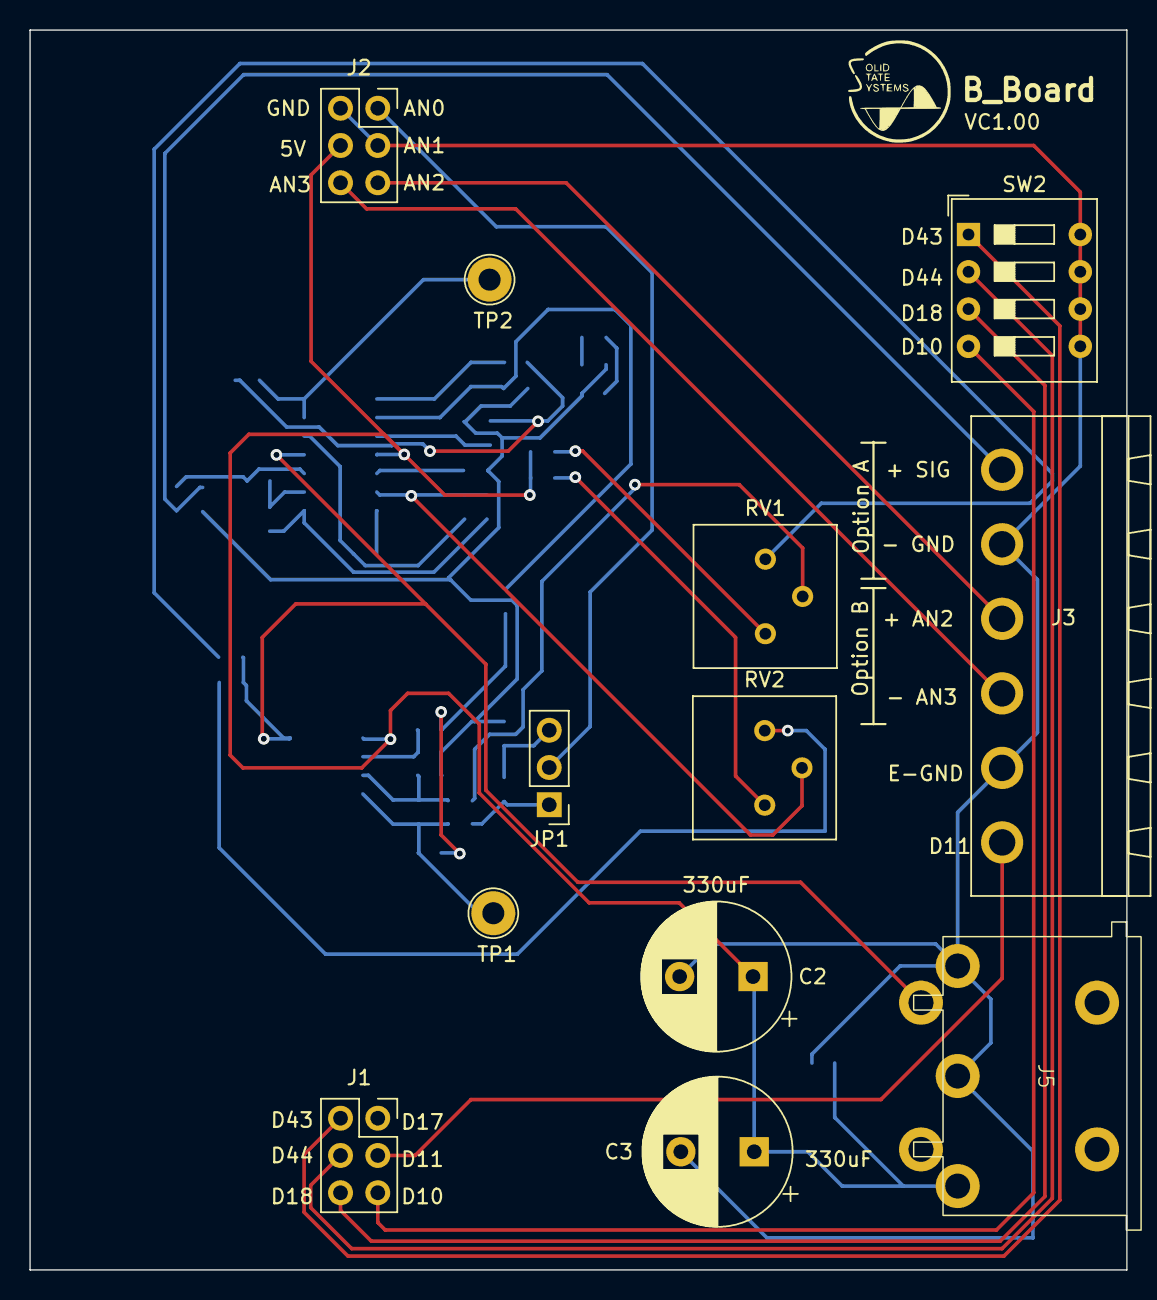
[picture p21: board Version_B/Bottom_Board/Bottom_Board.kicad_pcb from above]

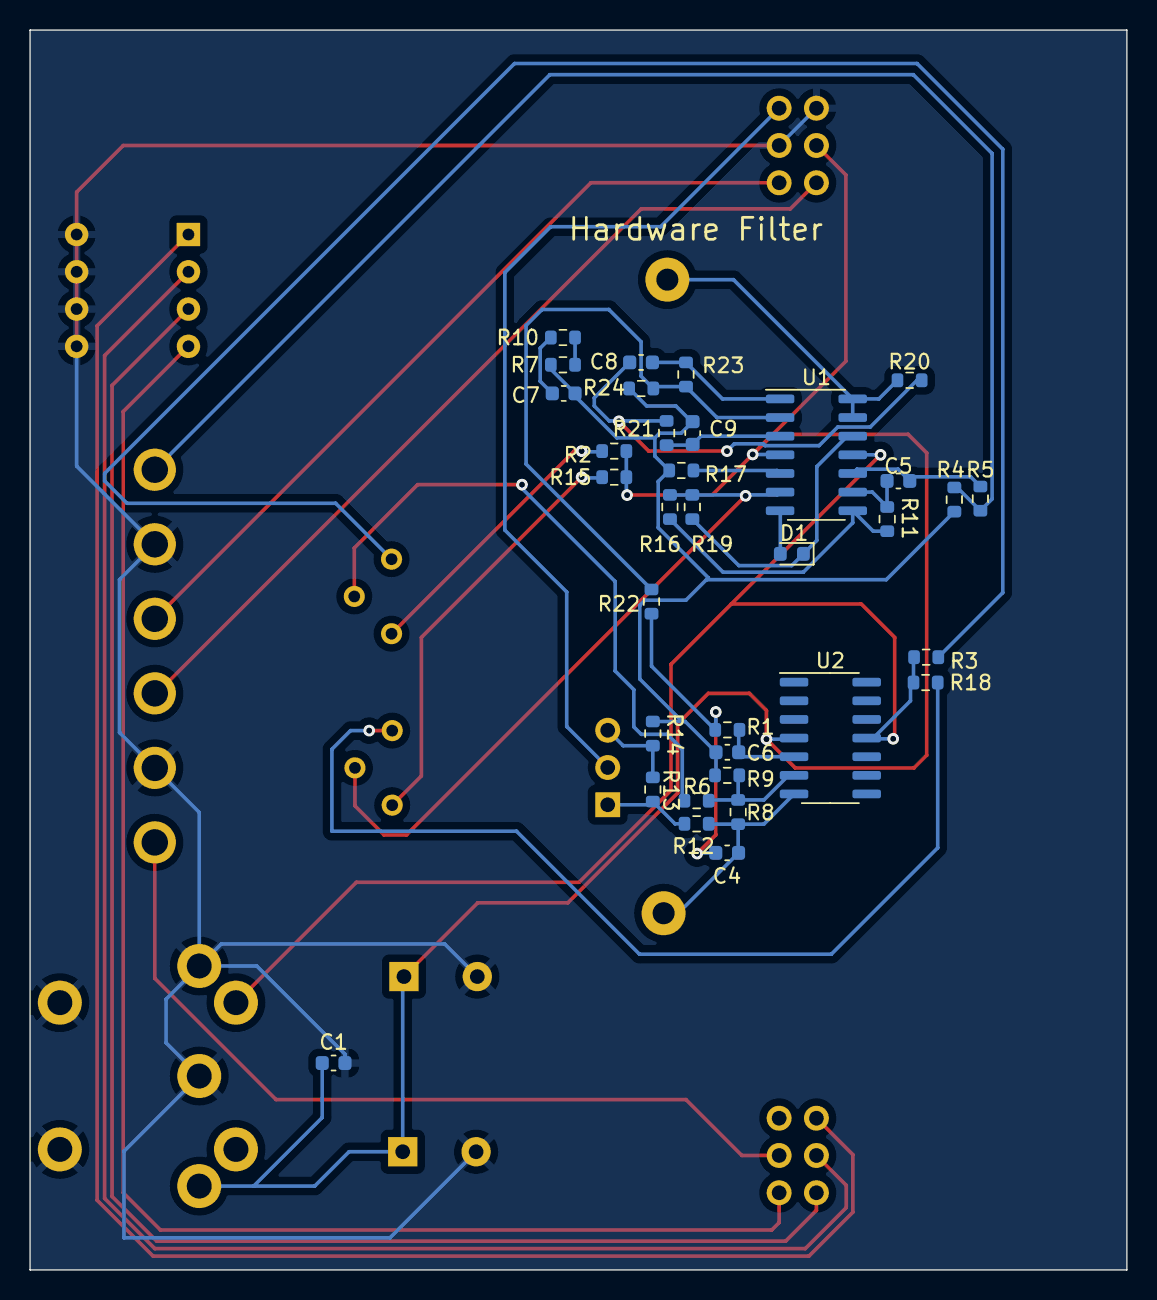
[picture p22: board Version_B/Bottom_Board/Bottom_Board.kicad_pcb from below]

Board: 2 copper layers, 74.8 x 84.5 mm, 46 parts (34 on the bottom side), 38 nets.

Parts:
C1, C8, C9: .1uF; C_0603_1608Metric
C2, C3: 330uF; CP_Radial_D10.0mm_P5.00mm
C4, C6: 0.1uF; C_0603_1608Metric
C5: .002uF; C_0603_1608Metric
C7: 0.1 uF; C_0603_1608Metric
D1: 1N914; D_0603_1608Metric
J1, J2: Conn_02x03_Top_Bottom; PinSocket_2x03_P2.54mm_Vertical
J3: Screw_Terminal_01x06; PhoenixContact_MSTBA_2,5_6-G-5,08_1x06_P5.08mm_Horizontal
J5: DIN-5; DIN_5_PIN
JP1: Jumper_3_Open; PinHeader_1x03_P2.54mm_Vertical
R1, R20, R21, R22: 80.6K; R_0603_1608Metric
R2, R17: 4.7K; R_0603_1608Metric
R3, R9, R13, R14, R16, R19, R24: 10K; R_0603_1608Metric
R4: 30.1K; R_0603_1608Metric
R5: 20K; R_0603_1608Metric
R6: 1M; R_0603_1608Metric
R7: 25.5K; R_0603_1608Metric
R8: 3.65K; R_0603_1608Metric
R10: 187K; R_0603_1608Metric
R11: 110K; R_0603_1608Metric
R12: 16.2K; R_0603_1608Metric
R15, R18: 22K; R_0603_1608Metric
R23: 1.82K; R_0603_1608Metric
RV1, RV2: 20K; Potentiometer_Bourns_3386P_Vertical
SW2: SW_DIP_x04; SW_DIP_SPSTx04_Slide_9.78x12.34mm_W7.62mm_P2.54mm
TP1: .75 Vdc; TestPoint_Loop_D2.54mm_Drill1.5mm_Beaded
TP2: .55 Vdc; TestPoint_Loop_D2.54mm_Drill1.5mm_Beaded
U1, U2: LM324; SOIC-14_3.9x8.7mm_P1.27mm

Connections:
2x_OUTPUT: JP1.1 (A), R12.1, R13.2
4x_OUTPUT: JP1.3 (B), R13.1, R14.2
5V: C1.1, C2.1, C3.1, J2.4, J5.3, R2.2, R15.1, U1.4 (V+), U2.4 (V+)
-5V: J5.4, R3.1, R18.2, U1.11 (V-), U2.11 (V-)
AN0: J2.1, JP1.2 (C)
AN1: C1.2, C2.2, C3.2, J2.2, J2.3, J3.2, J3.5, J5.1, J5.2, J5.6, J5.7, SW2.5, SW2.6, SW2.7, SW2.8
AN2: J2.5, J3.4
AN3: J2.6, J3.3
D10: J1.5, SW2.4
D11: J1.3, J3.1
D18: J1.6, SW2.3
D43: J1.2, SW2.1
D44: J1.4, SW2.2
E23_INPUT: J3.6, R4.1, R5.1
E60: C6.1, C7.2, C9.2, R4.2, R7.2, R9.1, R14.1, R17.2, R24.2
unnamed: C4.1, R8.2, R12.2, TP1.1, U2.7
unnamed: C4.2, R1.1, R22.1
unnamed: C7.1, R10.2
unnamed: C8.1, R23.2, U1.1
unnamed: C8.2, R20.2, R21.1
unnamed: D1.2 (A), U1.7
unnamed: D1.1 (K), R19.2, U1.12 (+)
unnamed: R2.1, RV1.1
unnamed: R3.2, RV1.3
unnamed: R6.2, RV1.2
unnamed: R7.1, R10.1
unnamed: R11.2, R16.1, U1.8
unnamed: R15.2, RV2.1
unnamed: R18.1, RV2.3
unnamed: C9.1, R21.2, U1.3 (+)
unnamed: R22.2, R23.1, R24.1, U1.2 (-)
unnamed: R17.1, U1.5 (+)
unnamed: R16.2, R19.1, RV2.2, U1.6 (-)
unnamed: C5.2, R5.2, U1.10 (+)
unnamed: C5.1, R11.1, U1.9 (-)
unnamed: R20.1, TP2.1, U1.13 (-), U1.14
unnamed: C6.2, R1.2, U2.5 (+)
unnamed: R6.1, R8.1, R9.2, U2.6 (-)

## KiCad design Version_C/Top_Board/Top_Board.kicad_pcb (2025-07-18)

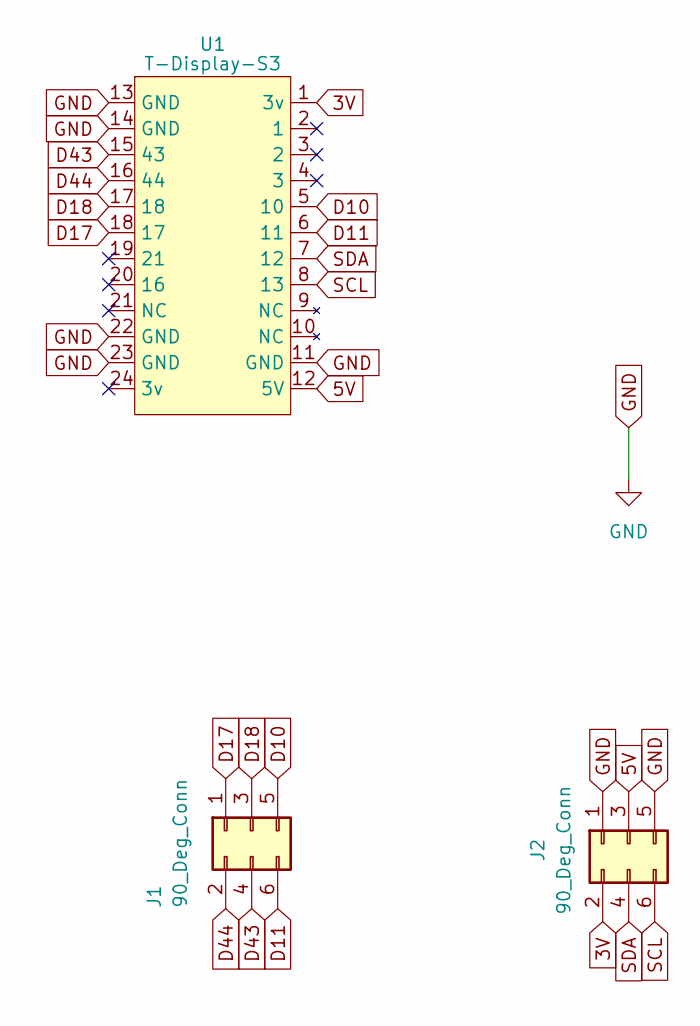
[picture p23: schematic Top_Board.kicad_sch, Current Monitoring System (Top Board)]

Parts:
J1, J2: 90_Deg_Conn; PinHeader_2x03_P2.54mm_Horizontal
U1: T-Display-S3

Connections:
3V: J2.2, U1.1 (3v)
5V: J2.3, U1.12 (5V)
D10: J1.5, U1.5 (10)
D11: J1.6, U1.6 (11)
D17: J1.1, U1.18 (17)
D18: J1.3, U1.17 (18)
D43: J1.4, U1.15 (43)
D44: J1.2, U1.16 (44)
GND: J2.1, J2.5, U1.11 (GND), U1.13 (GND), U1.14 (GND), U1.22 (GND), U1.23 (GND)
SCL: J2.6, U1.8 (13)
SDA: J2.4, U1.7 (12)

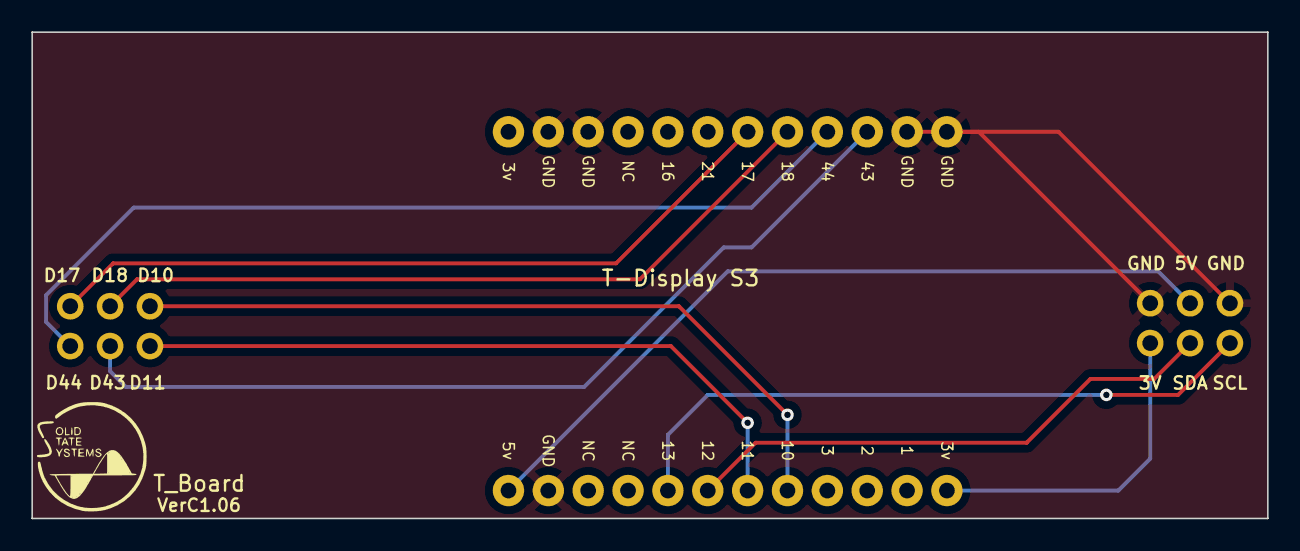
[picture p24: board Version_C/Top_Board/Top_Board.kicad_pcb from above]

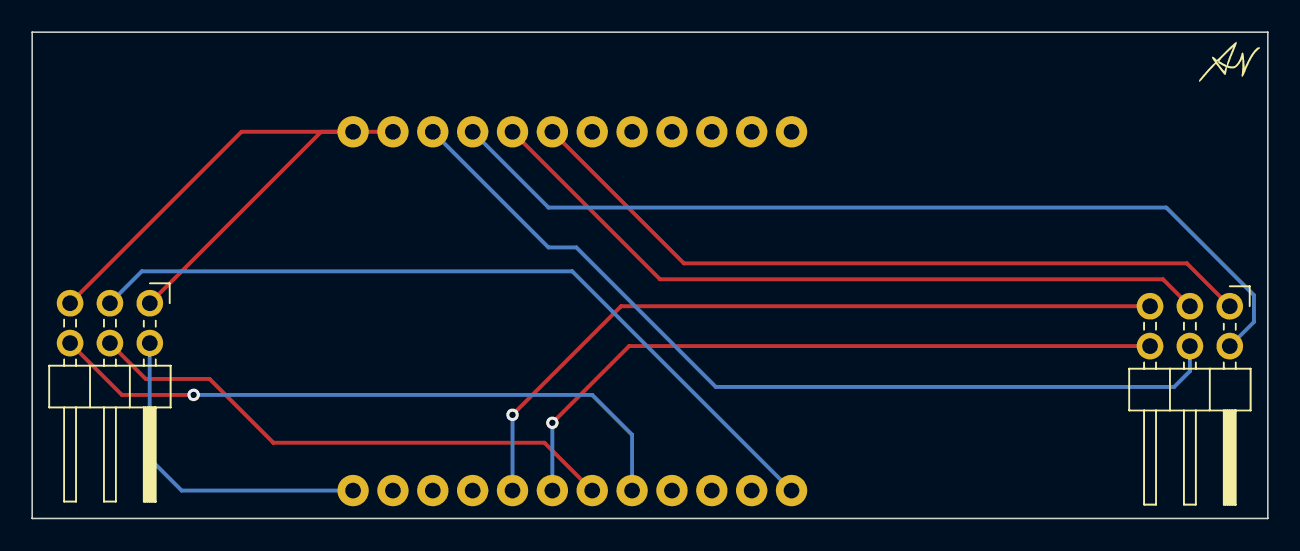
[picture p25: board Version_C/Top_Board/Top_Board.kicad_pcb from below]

Board: 2 copper layers, 78.7 x 31.0 mm, 3 parts (2 on the bottom side), 11 nets.

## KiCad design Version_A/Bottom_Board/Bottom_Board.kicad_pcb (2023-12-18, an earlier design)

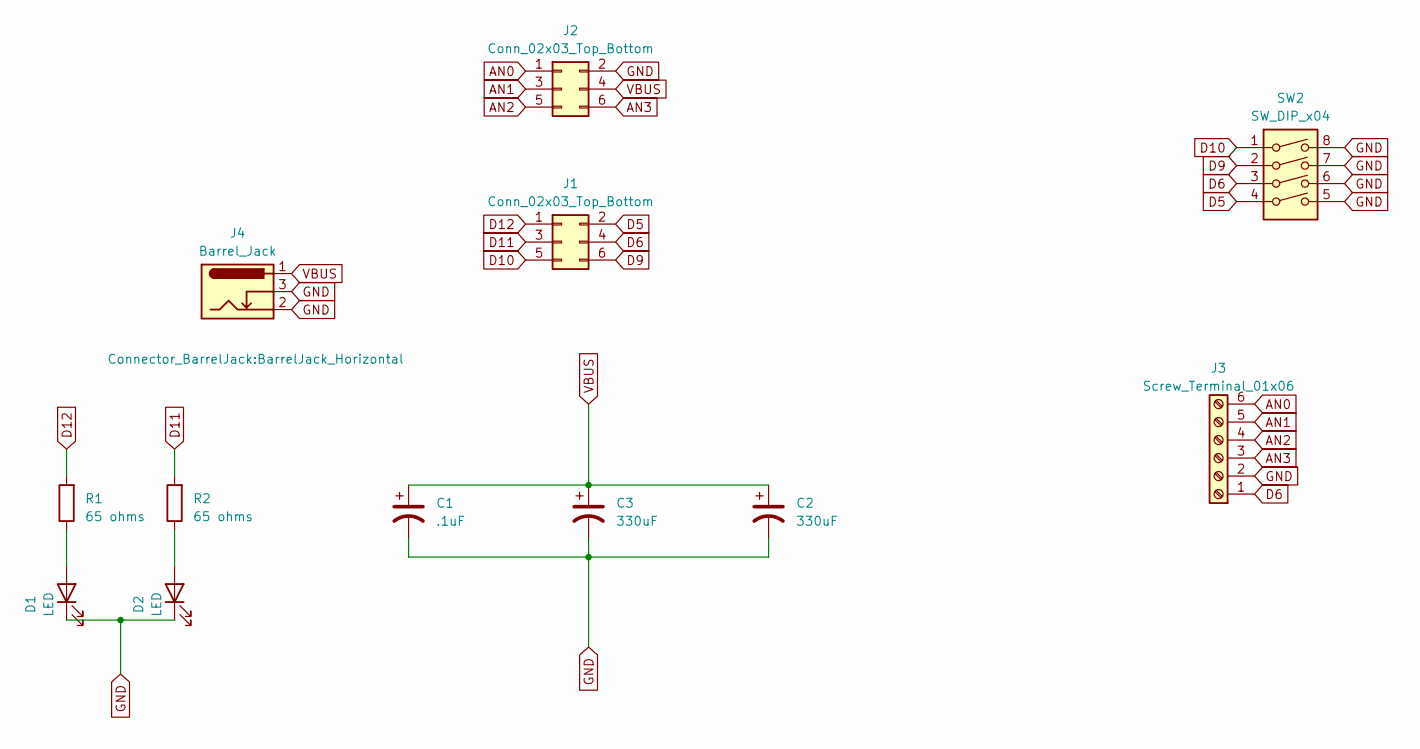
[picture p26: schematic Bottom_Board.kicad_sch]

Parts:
C1: .1uF; C_Disc_D3.8mm_W2.6mm_P2.50mm
C2, C3: 330uF; CP_Radial_D10.0mm_P5.00mm
D1, D2: LED; LED_D3.0mm_Horizontal_O3.81mm_Z10.0mm
J1, J2: Conn_02x03_Top_Bottom; PinSocket_2x03_P2.54mm_Vertical
J3: Screw_Terminal_01x06; PhoenixContact_MSTBA_2,5_6-G-5,08_1x06_P5.08mm_Horizontal
J4: Barrel_Jack; BarrelJack_Horizontal
R1, R2: 65 ohms; R_Axial_DIN0411_L9.9mm_D3.6mm_P12.70mm_Horizontal
SW2: SW_DIP_x04; SW_DIP_SPSTx04_Slide_9.78x12.34mm_W7.62mm_P2.54mm

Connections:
AN0: J2.1, J3.6
AN1: J2.3, J3.5
AN2: J2.5, J3.4
AN3: J2.6, J3.3
D5: J1.2, SW2.4
D6: J1.4, J3.1, SW2.3
D9: J1.6, SW2.2
D10: J1.5, SW2.1
D11: J1.3, R2.2
D12: J1.1, R1.2
GND: C1.2, C2.2, C3.2, D1.1 (K), D2.1 (K), J2.2, J3.2, J4.2, J4.3, SW2.5, SW2.6, SW2.7, SW2.8
unnamed: D1.2 (A), R1.1
unnamed: D2.2 (A), R2.1
VBUS: C1.1, C2.1, C3.1, J2.4, J4.1

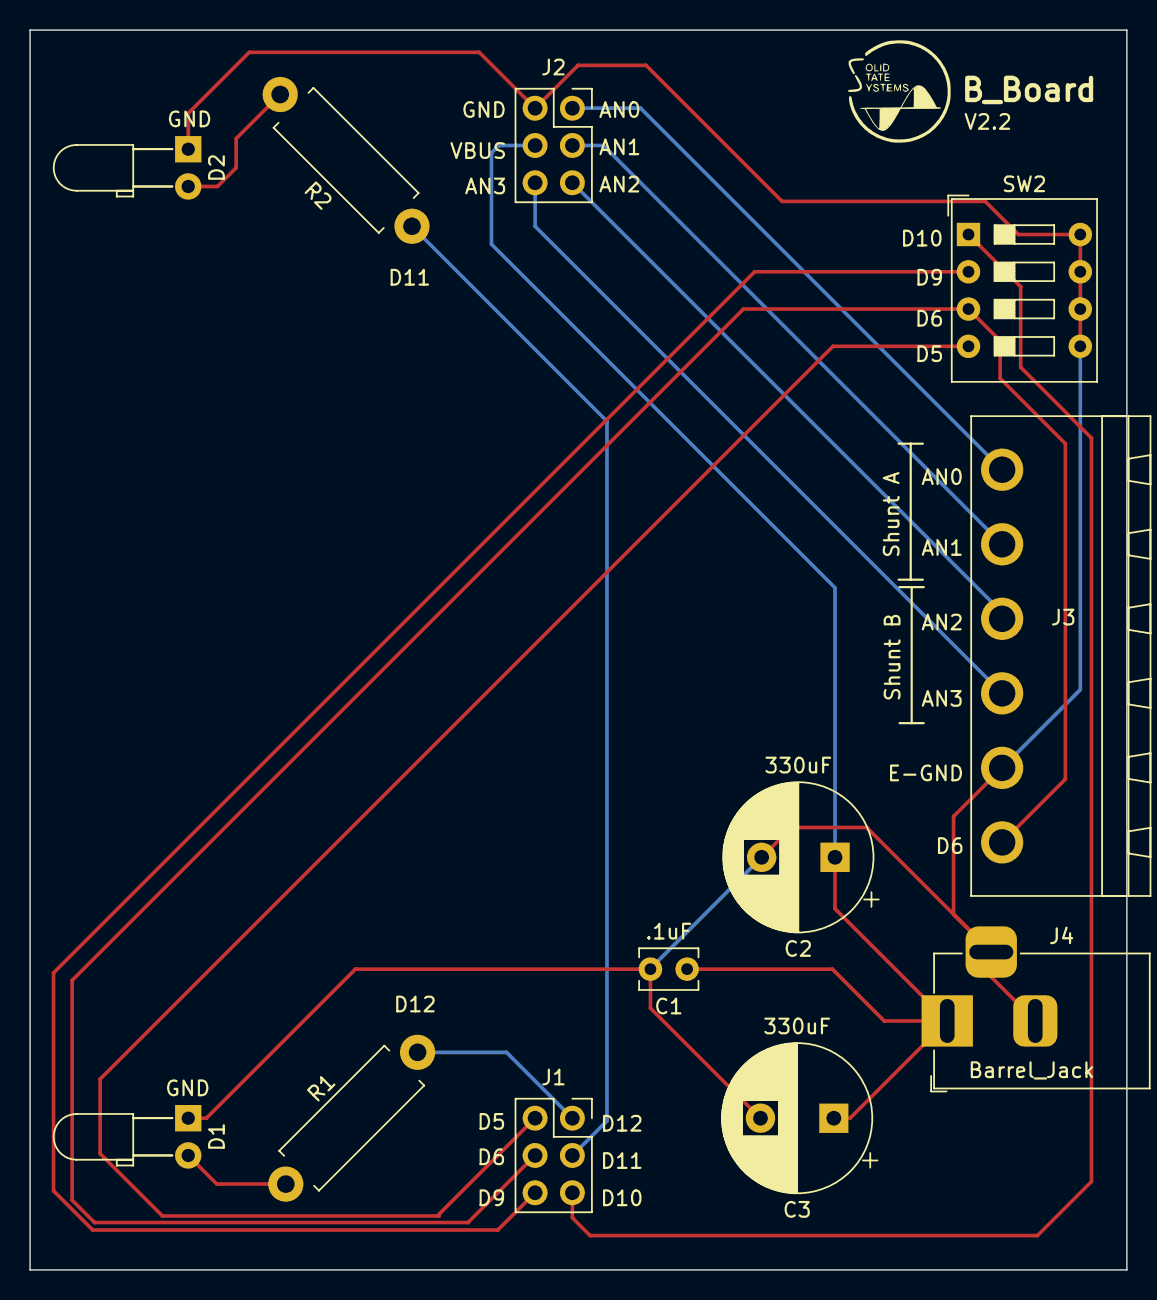
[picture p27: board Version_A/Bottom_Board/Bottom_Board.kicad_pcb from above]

Board: 2 copper layers, 74.8 x 84.5 mm, 12 parts (0 on the bottom side), 14 nets.

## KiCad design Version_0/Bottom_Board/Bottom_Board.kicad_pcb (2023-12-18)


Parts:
J1, J2: Conn_02x03_Top_Bottom; PinSocket_2x03_P2.54mm_Vertical
J3: Screw_Terminal_01x12; PhoenixContact_MSTBA_2,5_12-G-5,08_1x12_P5.08mm_Horizontal
J4: Barrel_Jack; BarrelJack_Horizontal

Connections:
A0: J2.2, J3.8
A1: J2.6, J3.7
A2: J2.4, J3.6
AN0: J1.2, J3.12
AN1: J1.1, J3.11
AN2: J1.3, J3.10
AN3: J1.5, J3.9
D5: J2.1, J3.5
D6: J2.3, J3.4
D9: J2.5, J3.3
GND: J1.4, J3.1, J4.2, J4.3
VBUS: J1.6, J3.2, J4.1


Board: 2 copper layers, 74.8 x 84.5 mm, 4 parts (0 on the bottom side), 12 nets.

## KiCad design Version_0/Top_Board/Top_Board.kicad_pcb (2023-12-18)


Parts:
ESP1: ESP32 S3 Feather; Combined Sockets_1x16_1x12
J1, J4: Conn_02x03_Top_Bottom; PinHeader_2x03_P2.54mm_Horizontal
J2: Conn_01x10_Socket; PinSocket_1x10_P2.54mm_Vertical_1
J3: Conn_02x01; PinHeader_1x02_P2.54mm_Vertical
R1, R4: R; R_0805_2012Metric
R2, R3: R; R_Axial_DIN0411_L9.9mm_D3.6mm_P12.70mm_Horizontal

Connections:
3.3V: ESP1.1 (3.3V), J2.10
A0: ESP1.4 (A0), J4.2
A1: ESP1.5 (A1), J4.6
A2: ESP1.6 (A2), J4.4
A3: ESP1.7 (A3)
A4: ESP1.8 (A4)
A5: ESP1.9 (A5)
ADDR: J2.6
ALRT: J2.5
AN0: J1.2, J2.4, R1.1, R2.1
AN1: J1.1, J2.3
AN2: J1.3, J2.2, R3.1, R4.1
AN3: J1.5, J2.1
D5: ESP1.25 (D5), J3.1, J4.1
D6: ESP1.24 (D6), J4.3
D9: ESP1.23 (D9), J4.5
D10: ESP1.22 (D10)
GND: ESP1.3 (GND), J1.4, J2.9, J3.2, R1.2, R2.2, R3.2, R4.2
MISO: ESP1.12 (MISO)
MOSI: ESP1.11 (MOSI)
RESET: ESP1.0 (RESET)
RX: ESP1.13 (RX)
SCK: ESP1.10 (SCK)
SCL: ESP1.26 (SCL), J2.8
SDA: ESP1.27 (SDA), J2.7
TX: ESP1.14 (TX)
TXDO: ESP1.15 (TXD0)
VBAT: ESP1.16 (VBAT)
VBUS: ESP1.18 (VBUS), J1.6

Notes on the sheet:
Note: Not Parallel Resistors, Top resistor for SMD and bottom resistor for THT



Board: 2 copper layers, 78.7 x 31.0 mm, 9 parts (8 on the bottom side), 15 nets.

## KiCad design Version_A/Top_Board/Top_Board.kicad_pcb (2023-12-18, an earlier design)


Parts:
ESP1: ESP32 S3 Feather; Combined Sockets_1x16_1x12
J1, J4: Conn_02x03_Top_Bottom; PinHeader_2x03_P2.54mm_Horizontal
J2: Conn_01x10_Socket; PinSocket_1x10_P2.54mm_Vertical_1
J3: Conn_02x01; PinHeader_1x02_P2.54mm_Vertical
R1, R4, R5, R7: R; R_0805_2012Metric
R2, R3, R6, R8: R; R_Axial_DIN0411_L9.9mm_D3.6mm_P12.70mm_Horizontal
RV1, RV2: R_Potentiometer; SSS_Potentiometer

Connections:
3.3V: ESP1.1 (3.3V), J2.10, RV1.1, RV2.1
A0: ESP1.4 (A0)
A1: ESP1.5 (A1)
A2: ESP1.6 (A2)
A3: ESP1.7 (A3)
A4: ESP1.8 (A4), RV1.2
A5: ESP1.9 (A5), RV2.2
ADDR: J2.6
ALRT: J2.5
AN0: J1.1, J2.4, R1.1, R2.1
AN1: J1.3, J2.3, R5.1, R6.1
AN2: J1.5, J2.2, R3.1, R4.1
AN3: J1.6, J2.1, R7.1, R8.1
D5: ESP1.25 (D5), J3.1, J4.2
D6: ESP1.24 (D6), J4.4
D9: ESP1.23 (D9), J4.6
D10: ESP1.22 (D10), J4.5
D11: ESP1.21 (D11), J4.3
D12: ESP1.20 (D12), J4.1
D13: ESP1.19 (D13)
GND: ESP1.3 (GND), J1.2, J2.9, J3.2, R1.2, R2.2, R3.2, R4.2, R5.2, R6.2, R7.2, R8.2, RV1.3, RV2.3
MISO: ESP1.12 (MISO)
MOSI: ESP1.11 (MOSI)
RESET: ESP1.0 (RESET)
RX: ESP1.13 (RX)
SCK: ESP1.10 (SCK)
SCL: ESP1.26 (SCL), J2.8
SDA: ESP1.27 (SDA), J2.7
TX: ESP1.14 (TX)
TXDO: ESP1.15 (TXD0)
VBAT: ESP1.16 (VBAT)
VBUS: ESP1.18 (VBUS), J1.4

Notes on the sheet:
Note: Not Parallel Resistors, Top resistor for SMD and bottom resistor for THT



Board: 2 copper layers, 78.7 x 31.0 mm, 15 parts (14 on the bottom side), 17 nets.

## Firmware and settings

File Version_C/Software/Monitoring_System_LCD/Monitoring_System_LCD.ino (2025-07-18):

/*
* Company: Solid State Systems
* Author: Aaron Nguyen
* Project: Monitoring System Version C (LCD + Hardware Filter)
*
* Description: Secured Solutions Group program using the LilyGo T-Display S3 (170x320 pixels) to make a custom ammeter/timer for client. Communicates with external ADC via I2C protocol using it to read differential
* voltage across varying shunts from 1000Amps/100mV to 1000Amps/25mV to detect the amperage. Uses software average and peak detector to obtain correct voltage. 
*
* DIP Switch Configuration
* "D44: Off, D43: Off" for 1000/100 shunt
* "D44: Off, D43: On" for 1000/50 shunt
* "D44: On, D43: Off" for 1000/25 shunt
* "D44: On, D43: On" for 1000/25 shunt
* 
* LCD uses SPI protocol to communicate
*
* 6/25/2023 Update: ADS 1115 gets around 1450 samples per second in the code while loop. This means for .18 seconds, there will be 261 samples. for 1 seconds, there will be 1450 samples
* 6/26/2023 Update: adding time correcting function: corrects time if while loop isn't exited as fast as it should be.  changed display to display 4 different config types for debugging. plotted test machine output and made formula
* to predict next amp values since theirs is not linear
*/
#include <Adafruit_ADS1X15.h>  // ADC Library
#include <CircularBuffer.h>    // Circular Buffer library to store voltage samples
#include <SPI.h>               // SPI Communication Interface
#include <TFT_eSPI.h>          // LILYGO Specific library, taken from Adafruit GFX
#include "FontsAndImages.h"    // Contains my custom fonts and images
#include <TFT_eWidget.h>       // Widget library
#include <PNGdec.h>            //PNG decoder library
#include <esp_task_wdt.h>

/* This is required on ESP32 to put the ISR in IRAM. Define as
empty for other platforms. Be careful - other platforms may have
 other requirements. */
#ifndef IRAM_ATTR
#define IRAM_ATTR
#endif

//35 seconds WDT
#define WDT_TIMEOUT 35
// #define WDT_TIMEOUT_SAMP 600

#define I2C_SDA 12           // I2C Data pin for ADC
#define I2C_SCL 13           // I2C Clock pin for ADC
#define MAX_IMAGE_WDITH 320  // Solid State Systems logo pixel width

//Debugging mode statements. Helps differentiate serial lines from serial lines only used for debugging.
#define DEBUG 1
//if in debugging mode then make each of these debug functions the same as a serial print.
#if DEBUG
#define debug(x) Serial1.print(x)
#define debugln(x) Serial1.println(x)

//all debug lines are equal to nothing
#else
#define debug(x)
#define debugln(x)
#endif


TFT_eSPI tft = TFT_eSPI();  // Use hardware SPI

//coordinates for various TFT display features (T-Display S3 is 170x320 pixels)
float ampX = 160;   // display x axis pixel coordinate
float ampY = 10;    // display x axis pixel coordinate
float timeX = 160;  // display x axis pixel coordinate
float timeY = 170;  // display y axis pixel coordinate
float voltX = 0;    // display x axis pixel coordinate
float voltY = 170;  // display y axis pixel coordinate

//Variables needed for Solid State Systems company Logo LCD display
PNG png;           // PNG decoder instance
int16_t xpos = 0;  // x-coordinate of logo
int16_t ypos = 0;  // y-coordinate of logo

// FREERTOS Mutex
SemaphoreHandle_t mutex;

Adafruit_ADS1115 ads;
char task0_string[50];               //string to hold display data, essential for serial and lcd
char task1_string[50];               //string to hold display data, essential for serial and lcd
const int WAVEFORM_MAX_SIZE = 2890;  // amount of samples stored. Number chosen for 1 seconds worth of samples. Sampling rate: 1450 samples/sec
const int SENS_SIZE = 10;            //size of array that checks for consistent voltage above threshold sensitivity
bool hardware_filter = 1;            // changes hardware filter; 0 is off and 1 is on
bool old_hardware_filter = 1;        // keeps track of previous hardware filter value in order to detect change

//Function used in the qsort function argument. Customize it based on what the size of the data type and if you want ascending sort or descending sort
int comp(const void *elem1, const void *elem2);

// Structure containing all data used to capture and modify the signal data
class SignalInfo {

private:
  float sensorVal = 0;         // sensorVal
  float startTime = 0;         // marked start time of waveform
  float endTime = 1;           // marked end time of waveform
  uint sample_count = 0;       // holds the count of samples
  float waveform_time = 0.11;  // The waveform's true length of time in seconds
  float displayTime = 0.11;    // Display time variable in seconds
  float enter_sens = .002;          // input sensitivity
  float exit_sens = .002;
  float latency = 0.0;  //0 ms latency (customizable)
  float counting_rate = 0;
  float ampPeak = 0.00;
  float voltPeak = 0;
  const float front_trunc = 0.4;       // 40% amount of samples truncated at the beginning part of the array storing sensor values.
  const float back_trunc = 0.2;        // 20% amount of samples truncated at the end part of the array storing sensor values.
  const float back_sort_trunc = .001;  // No HW Filter: .1% amount of samples truncated at the end part of the sorted array
  const float hw_front_trunc = 0.4;    // HW Filter: 20% amount of samples truncated at the beginning part of the array storing sensor values.
  const float hw_back_trunc = 0.4;     // HW Filter: 20% amount of samples truncated at the end part of the array storing sensor values
public:

  int shunt_multiplier = 1;                           // indicates what shunt is being used
  bool complete_flag = 0;                             // signifies complete waveform capture
  CircularBuffer<float, SENS_SIZE> sensBuffer;        //Buffer that checks filters out rare bad readings from good readings
  CircularBuffer<float, WAVEFORM_MAX_SIZE> Waveform;  //Buffer that checks filters out rare bad readings from good readings
  CircularBuffer<float, WAVEFORM_MAX_SIZE> *Waveformptr = &Waveform;



  //checks if valid waveform is exists (Essentially differentiates between a waveform or noise)
  bool waveform_exist() {

    esp_task_wdt_reset();
    float reading = ads.getLastConversionResults();
    sensBuffer.push(ads.computeVolts(reading)/2);  // polling for sensor values to see when there is actually significant voltage (voltage above the threshold value). Changing V to mV
      debug("SensorValue: ");
      debugln(ads.computeVolts(reading)/2)*1000;
      // debug("Raw Reading: ");
    // checks if last two values are from a valid waveform
    for (int i = SENS_SIZE - 2; i < SENS_SIZE; ++i) {
      if (abs(sensBuffer[i]) <= enter_sens) {
        return false;  // False, waveform does not exist, only low voltage detected
      }
    }
    return true;  // True, waveform exists, significant voltage detected
  }

  //capture waveform
  void waveform_capture() {
    Serial1.println("Circle On");
    tft.fillCircle(25, 145, 20, TFT_RED);
    esp_task_wdt_reset();
    Waveform.clear();  // Clears buffer so it doesn't have left over values
    sample_count = 0;
    startTime = millis();  //marks the beginning time of the waveform
      // if newest ADC readings below a certain sensitivity then end capture
    while (!(waveform_ended())) {
      float my_reading = ads.getLastConversionResults();
      sensorVal = ads.computeVolts(my_reading)/2;  // polling for sensor values to see when there is actually significant voltage (voltage above the threshold value)
      sample_count++;
      debug("SensorValue: ");
      debugln(sensorVal*1000);
      Waveform.push(sensorVal);
      sensBuffer.push(sensorVal);
    }

    // If samples are really low then return and
    if (sample_count < 200) {
      tft.fillScreen(TFT_BLACK);
      debugln("Low Samples");
      debugln("Circle Off");
      tft.fillCircle(25, 145, 20, TFT_BLACK);
      tft.setTextColor(TFT_RED);                 //Sets color of text to red
      tft.setFreeFont(AMPFONT70);                  // Selects the font
      tft.setTextDatum(TC_DATUM);                // Adjusts reference point of text generation to top center
      strcpy(task1_string, "00000");              // stores peak amp value into string to be printed to LCD
      tft.drawString(task1_string, ampX, ampY);  // Print the test text in the custom font
      return;
    }
    endTime = millis();  //signals end of timer
    set_volt_peak();     //sets the peak voltage of the waveform
    set_amp_peak();      // sets the peak amp value of the waveform
    print_wave_form();   //prints the waveform

    waveform_time = ((endTime - startTime) / 1000);
    counting_rate = sample_count / (waveform_time);

    displayTime = correct_time();  // Corrects time and outputs it to display
    displayTime += latency;        //accounts for latency issues in tracking
    debug("voltPeak: ");
    debugln(voltPeak);
    debug("Samples per second is: ");
    debugln(counting_rate);
    debug("The size is: ");
    debugln(Waveform.size());
    debug("The seconds is: ");
    debugln(waveform_time);

    Serial1.println("Circle Off");
    tft.fillCircle(25, 145, 20, TFT_BLACK);
    complete_flag = 1;
  }

  //checks if waveform ended (Sensor only picks up negligible voltages)
  bool waveform_ended() {
    // checks if last 8 values have been below the exit sensitivity threshold
    for (int i = sensBuffer.size() - 8; i < sensBuffer.size(); ++i) {
      if (abs(sensBuffer[i]) > exit_sens) {
        return false;  // False, waveform has not ended
      }
    }
    return true;  // True, Waveform has ended
  }
  //returns display time
  float timerDisplay() {
    return displayTime;
  }
  //Prints values inside wwaveform
  void print_wave_form() {
    for (int i = 0; i < Waveform.size(); ++i) {
      // sprintf(task0_string, "Array Value[%d] = %.0f", i, Waveform[i]);
      // debugln(task0_string);
    }
  }


  /* Corrects display time from being too long due to while loop not exiting correctly
 Takes an array pointer as an argument, peak value, and sampling rate
 Reverse iterates through the array until peak value is reached, counts how many elements
 it iterated through then subtracts that from display time */
  //=========================================v==========================================
  float correct_time() {
    int iterate_count = 0;
    for (int i = (Waveform.size() - 1); i >= 0; --i) {
      //if value is greater than 90% of peak value, break out of for loop
      if (Waveform[i] > (.9 * voltPeak)) {
        break;
      }
      iterate_count++;
    }
    return (waveform_time - (iterate_count / counting_rate));
  }

  //Takes in circular buffer of graph points and returns the peak of the buffer
  float set_volt_peak() {
    int wave_size = Waveform.size();  //size of waveform

    //Variables deciding how much of the waveform to modify based on how long waveform is
    int wave_start = .4 * wave_size;       //Cuts the front of waveform by changing the index the sort begins
    int wave_end = .2 * wave_size;         //Cuts the back of waveform by ending for loop early
    int wave_sort_end = .001 * wave_size;  //Cuts any peak values from minor noise

    // Truncate 40% off front and 20% off back. Sort. Cut .1% off peak value and return peak value
    CircularBuffer<float, WAVEFORM_MAX_SIZE> Sorted_Waveform;

    for (int i = wave_start; i < (wave_size - wave_end); ++i) {
      Sorted_Waveform.push(Waveform[i]);
    }

    qsort(&Sorted_Waveform, Sorted_Waveform.size() + 1, sizeof(float), comp);  //qsort has strange bug where last entry in array is not sorted
    voltPeak = Sorted_Waveform[Sorted_Waveform.size() - 2 - wave_sort_end];    // - 1 for index starting at 0 and -1 for qsort bug mentioned in above comment
    for (int i = 0; i < Sorted_Waveform.size(); ++i) {
      // sprintf(task0_string, "Sorted Value[%d] = %.0f", i, Sorted_Waveform[i]);
      // debugln(task0_string);
    }
    Sorted_Waveform.clear();
    return voltPeak;
  }

  /* returns the peak amps for the waveform depending on what shunt is attached */
  float set_amp_peak() {
    ampPeak = shunt_multiplier * volt_peak()*1000;
    return ampPeak;
  }

  /*returns the peak amps for the waveform */
  float amp_peak() {
    return ampPeak;
  }

  /*returns the peak amps for the waveform */
  float volt_peak() {
    return voltPeak;
  }
  /* Function that converts peak mv to Amps using a formula made from excel plots of legacy build. 
    Old build had similar amp readings but not quite the same. used a formula to adjust for its error*/
  float Amp_peak_legacy() {
    return (1000 * (-0.000653 + 0.00324 * voltPeak + 0.00000841 * voltPeak * voltPeak));  //2nd polynomial formula.
  }
} wave;

//Draws png for company logo
void pngDraw(PNGDRAW *pDraw);

//LCD Text Display functions
void amp_display(const GFXfont *font);
void time_display(const GFXfont *font);


//INTERRUPTS
void IRAM_ATTR CONFIG_INTERRUPT();  // interrupt that will call reconfigure function
void IRAM_ATTR ADS_READING();       // Changes between hardware filter and no hardware filter

//read the dip switches and change the multiplier of the voltage to amps based on the dip switch readings
void reconfigure();


// Core definitions (Used for dual-core ESP32)
static const BaseType_t pro_cpu = 0;  // Core 0
static const BaseType_t app_cpu = 1;  // Core 1

// Pins
static const int pin_1 = 38;  // LED pin

// Globals
static SemaphoreHandle_t bin_sem;

// Tasks

// Task in Core 0
void doTask0(void *parameters) {

  // Subscribe this task to TWDT, then check if it is subscribed
  ESP_ERROR_CHECK(esp_task_wdt_add(NULL));
  ESP_ERROR_CHECK(esp_task_wdt_status(NULL));

  while (1) {

    if (xSemaphoreTake(mutex, 0) == pdTRUE) {
      if (wave.waveform_exist()) {
        wave.waveform_capture();
      }
      xSemaphoreGive(mutex);
    }
  }
}

// Task in Core 1
void doTask1(void *parameters) {
  // Subscribe this task to TWDT, then check if it is subscribed
  ESP_ERROR_CHECK(esp_task_wdt_add(NULL));
  ESP_ERROR_CHECK(esp_task_wdt_status(NULL));

  // Do forever
  while (1) {
    esp_task_wdt_reset();
    if (xSemaphoreTake(mutex, 0) == pdTRUE) {
      if (wave.complete_flag == 1) {
        wave.complete_flag = 0;
        tft.fillScreen(TFT_BLACK);  // Clear screen

        // if amp display more than 4 digits then change font size to smaller size
        if (wave.amp_peak() > 9999) {
          amp_display(AMPFONT);  // displays amp in top center of LCD
        } else {
          amp_display(AMPFONT);  // displays amps in top center of LCD
        }
        time_display(TIMEFONT);  //displays time in bottom right of LCD
      }
      tft.setTextColor(TFT_RED);                 //Sets color of text to red
      tft.setFreeFont(MYFONT25);                 // Selects the font
      tft.setTextDatum(BR_DATUM);                // Adjusts reference point of text generation to top center
   memset(task1_string, '\0', sizeof(task1_string));
      strcpy(task1_string, "AMPx1000");            // stores peak amp value into string to be printed to LCD
      tft.drawString(task1_string, ampX, ampY);  // Print the test text in the custom font
      xSemaphoreGive(mutex);                     // give away mutex
    }
  }
}
//*****************************************************************************
// Main (runs as its own task with priority 1 on core 1)

void setup() {


  pinMode(15, OUTPUT);  // to boot with battery...
  digitalWrite(15, 1);  // and/or power from 5v rail instead of USB
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
void loop() {
  vTaskDelete(NULL);
}

//Function used in the qsort function argument. Customize it based on what the size of the data type and if you want ascending sort or descending sort. (float and ascending sort is used here)
int comp(const void *elem1, const void *elem2) {
  float f = *((float *)elem1);
  float s = *((float *)elem2);
  if (f > s) return 1;
  if (f < s) return -1;
  return 0;
}


/*
 PNG function taken from example libraries
 This next function will be called during decoding of the png file to
 render each image line to the TFT.  If you use a different TFT library
 you will need to adapt this function to suit.
 Callback function to draw pixels to the display */
void pngDraw(PNGDRAW *pDraw) {
  uint16_t lineBuffer[MAX_IMAGE_WDITH];
  png.getLineAsRGB565(pDraw, lineBuffer, PNG_RGB565_BIG_ENDIAN, 0xffffffff);
  tft.pushImage(xpos, ypos + pDraw->y, pDraw->iWidth, 1, lineBuffer);
}

// Function that displays current at top center of LCD
void amp_display(const GFXfont *font) {

  tft.setTextColor(TFT_RED);                       //Sets color of text to red
  tft.setFreeFont(font);                           // Selects the font
  tft.setTextDatum(TC_DATUM);                      // Adjusts reference point of text generation to top center
  int amp_val = wave.amp_peak();
  amp_val = amp_val/10*10; //round down last value
  sprintf(task1_string, "%.0f", (float)amp_val);  // stores peak amp value into string to be printed to LCD
  tft.drawString(task1_string, ampX, ampY);        // Print the test text in the custom font
}

// Function that displays time in bottom right corner of LCD
void time_display(const GFXfont *font) {

  tft.setTextColor(TFT_WHITE);                                // Sets color of text to white
  tft.setFreeFont(font);                                      // Selects the font
  tft.setTextDatum(BC_DATUM);                                 //Adjusts reference point of text generation to bottom right
  sprintf(task1_string, "%.2f%s", wave.timerDisplay(), "s");  // stores corrected time value into string to be printed to LCD

  //Check that corrected time is above 0 seconds. If time negative then print N/A instead
  if (wave.timerDisplay() > 0) {
    tft.drawString(task1_string, timeX, timeY);  // prints string to LCD screen
  } else {
    tft.drawString("N/A", timeX, timeY);  // prints string to LCD screen
  }
}


//===================================================================================
//-------------------DIP SWITCH RECONFIGURATION-------------------------
//===================================================================================
// interrupt that will call reconfigure function
void IRAM_ATTR CONFIG_INTERRUPT() {
  reconfigure();
}
void IRAM_ATTR ADS_READING() {
  hardware_filter = !hardware_filter;
}
// read the dip switches and change the multiplier of the voltage to amps based on the dip switch readings
void reconfigure() {
  int mtp[4];  //array for storing multiplexer DIP SWITCH values. Used to configure start up settings like what the multiplier value will be
  mtp[0] = digitalRead(44);
  mtp[1] = digitalRead(43);
  mtp[2] = digitalRead(11);
  mtp[3] = digitalRead(10);
  if (mtp[0] == 1 && mtp[1] == 1) {
    wave.shunt_multiplier = 10;  //D44 Off, D43 Off
  } else if (mtp[0] == 1 && mtp[1] == 0) {
    wave.shunt_multiplier = 20;  // D44 Off, D43 On
  } else if (mtp[0] == 0 && mtp[1] == 1) {
    wave.shunt_multiplier = 40;  //D44 On, D43 Off

  } else if (mtp[0] == 0 && mtp[1] == 0) {
    wave.shunt_multiplier = 40;  //D44 On, D43 On
  } else {
    wave.shunt_multiplier = 50;  //D44 On, D43 On
  }
  hardware_filter = 1;  // make hardware filter reading always active
}

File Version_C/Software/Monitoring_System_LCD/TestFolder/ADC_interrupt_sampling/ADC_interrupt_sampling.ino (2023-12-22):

#include <Adafruit_ADS1X15.h>  // ADC Library

#define I2C_SDA 12  // I2C Data pin for ADC
#define I2C_SCL 13  // I2C Clock pin for ADC
Adafruit_ADS1015 ads;
// Pin connected to the ALERT/RDY signal for new sample notification.
constexpr int READY_PIN = 1;

// This is required on ESP32 to put the ISR in IRAM. Define as
// empty for other platforms. Be careful - other platforms may have
// other requirements.
#ifndef IRAM_ATTR
#define IRAM_ATTR
#endif

volatile bool new_data = false;
void IRAM_ATTR NewDataReadyISR() {
  new_data = true;
}

float counter = 0;
float timeStart = 0;
float timeEnd = 0;
bool flag = 0;
float timeFinal = 0;
void setup() {
  // put your setup code here, to run once:
  Serial.begin(250000);
  Wire.begin(I2C_SDA, I2C_SCL);  // Initializes communication with ADC
  if (!ads.begin()) {
    while (1) {
      Serial.println("Failed to initialize ADS.");
      delay(3000);
    }
  }
  pinMode(READY_PIN, INPUT);
  // We get a falling edge every time a new sample is ready.
  attachInterrupt(digitalPinToInterrupt(READY_PIN), NewDataReadyISR, FALLING);
  ads.startADCReading(ADS1X15_REG_CONFIG_MUX_DIFF_0_1, /*continuous=*/true);
  Serial.println("Set up complete");
  ads.setDataRate(RATE_ADS1015_3300SPS);
  timeStart = millis();
}

void loop() {
  while (counter < 10000) {
    // If we don't have new data, skip this iteration.
    if (!new_data) {
      continue;
    }
    float sensorVal = ads.getLastConversionResults();
    new_data = false;
    ++counter;
  }
  if (flag == 0){
  timeEnd = millis();
  timeFinal = (timeEnd - timeStart) / 1000;
  Serial.print("Final time is: ");
  Serial.println(timeFinal);
  Serial.print("Samples per second is: ");
  Serial.println(counter / timeFinal);
}  flag = 1;
}

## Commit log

2023-09-01 work comp sample
    [1. Disk 1 (edited).SLDPRT, 1. PAN & TILT MOUNT.SLDASM, 2. Base.SLDPRT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]
2023-12-18 Legacy Repository
    [Pacman.SLDPRT]
2023-12-18 rework of project directory
    [1. Disk 1 (edited).SLDPRT, 1. PAN & TILT MOUNT.SLDASM, 16Bit I2C ADC+PGA - ADS1115.stp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]
2023-12-18 organization updates
    [DisplayBoard.sch]
2023-12-19 updated board b
    [Bottom_Board.kicad_pcb, Hardware_Filter.kicad_sch]
2023-12-19 added hardware filter simulation
2023-12-20 adjusted hardware values
    [Hardware_Filter.kicad_sch]
2023-12-20 freeRTOS rework with Waveform class function and reorganization of folder
    [DisplayBoard.sch]
2023-12-24 updated simulation circuit and finalized hardware design?
    [Bottom_Board.kicad_pcb, Bottom_Board.kicad_sch, Hardware_Filter.kicad_sch]
2024-01-05 connected e60 ground and an1
    [Bottom_Board.kicad_pcb, Bottom_Board.kicad_sch]
2024-01-15 added config switch for hardware filter on and off
2024-01-17 fixed timing issue and made averaging for HW Filter
    [Monitoring_System_LCD.ino]
2024-01-19 triangle wave simulation
    [Hardware_Filter.kicad_sch]
2024-02-19 1st test for better accuracy
    [Bottom_Board.kicad_pcb, Hardware_Filter.kicad_sch]
2024-02-20 working software filter
2024-02-20 changed 5 pin to 4 pin term block
    [Bottom_Board.kicad_pcb, Bottom_Board.kicad_sch]
2024-02-20 soft pcb changes: 90 degree term block, din connector scooted in, connected grounds
    [Bottom_Board.kicad_pcb]
2024-02-24 ads1015 on bottom board and aesthetic changes
    [4_Pin_Terminal_Block.stp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]
2024-02-25 autosaves and csv
    [Bottom_Board.csv]
2024-02-26 kicad 8.0 file
    [Bottom_Board.kicad_pcb, Bottom_Board.kicad_sch, Hardware_Filter.kicad_sch]
2024-03-03 csv file change and code update
    [Soldering Printout.csv]
2024-03-04 readjusted graphics and dip switches, increased serial rate, opened d17,d18 tx rx
2024-03-06 added flash folder and adjusted GUI
    [Bottom_Board.csv, Bottom_Board.kicad_sch, Hardware_Filter.kicad_sch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]
2024-03-15 minor fixe
    [Bottom_Board.kicad_pcb, Bottom_Board.kicad_sch, Hardware_Filter.kicad_sch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]
2024-03-19 updated jlpcb format
    [Bottom_Board-B_Cu.gbr, Bottom_Board-B_Mask.gbr, Bottom_Board-B_Paste.gbr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]
2024-03-24 aesthetic changes
    [Bottom_Board-B_Cu.gbr, Bottom_Board-B_Mask.gbr, Bottom_Board-B_Paste.gbr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]
2025-07-18 fixed directory overwrite
    [4_Pin_Terminal_Block.stp, BoM_9-9-24.csv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]
